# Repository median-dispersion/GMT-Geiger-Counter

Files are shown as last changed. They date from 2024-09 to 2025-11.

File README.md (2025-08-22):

# GMT-Geiger-Counter

## ⚠️ DISCLAIMER

This is a hobby project and should not be relied upon to accurately determine radiation levels, especially not if those radiation levels are potentially dangerous and or lethal!

## 🖼️ Images

<p align="center">
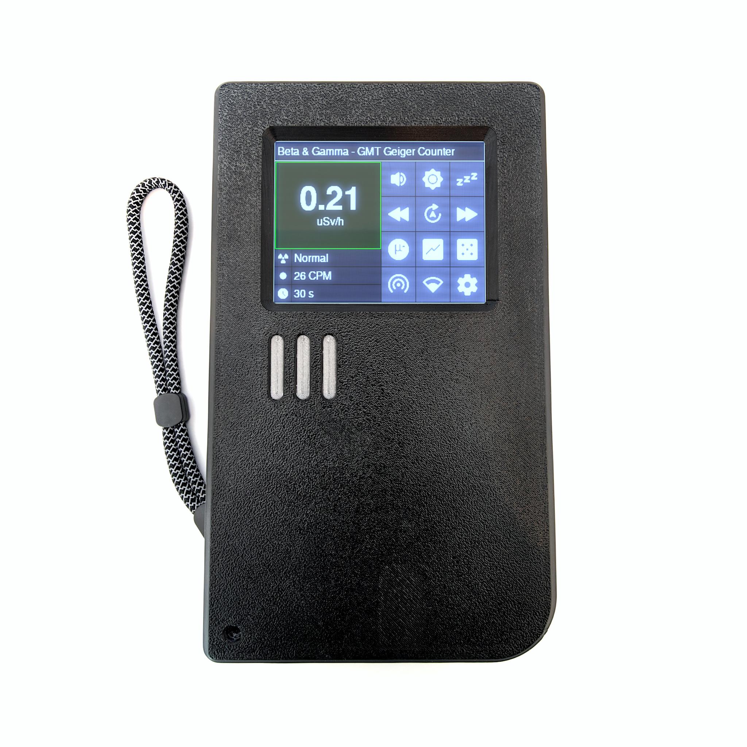
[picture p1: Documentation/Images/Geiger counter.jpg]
Geiger counter
    
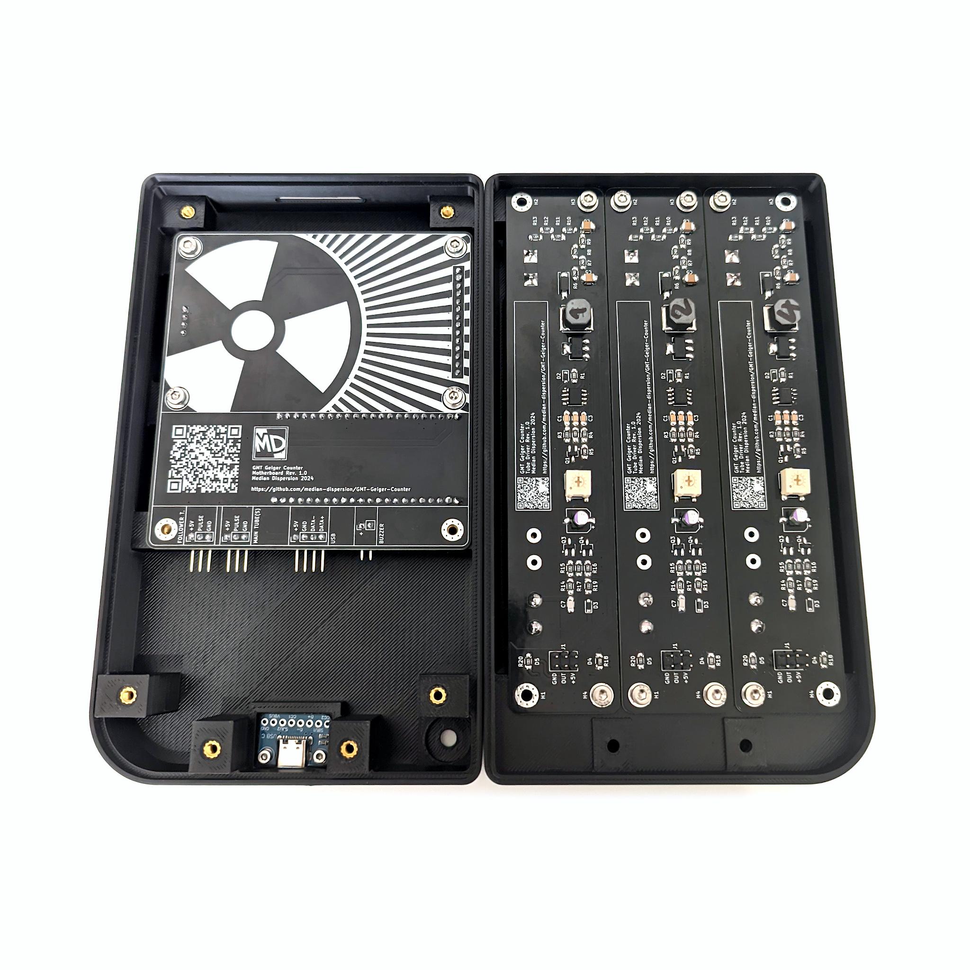
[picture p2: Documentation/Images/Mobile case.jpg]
Mobile case
    
    <br>
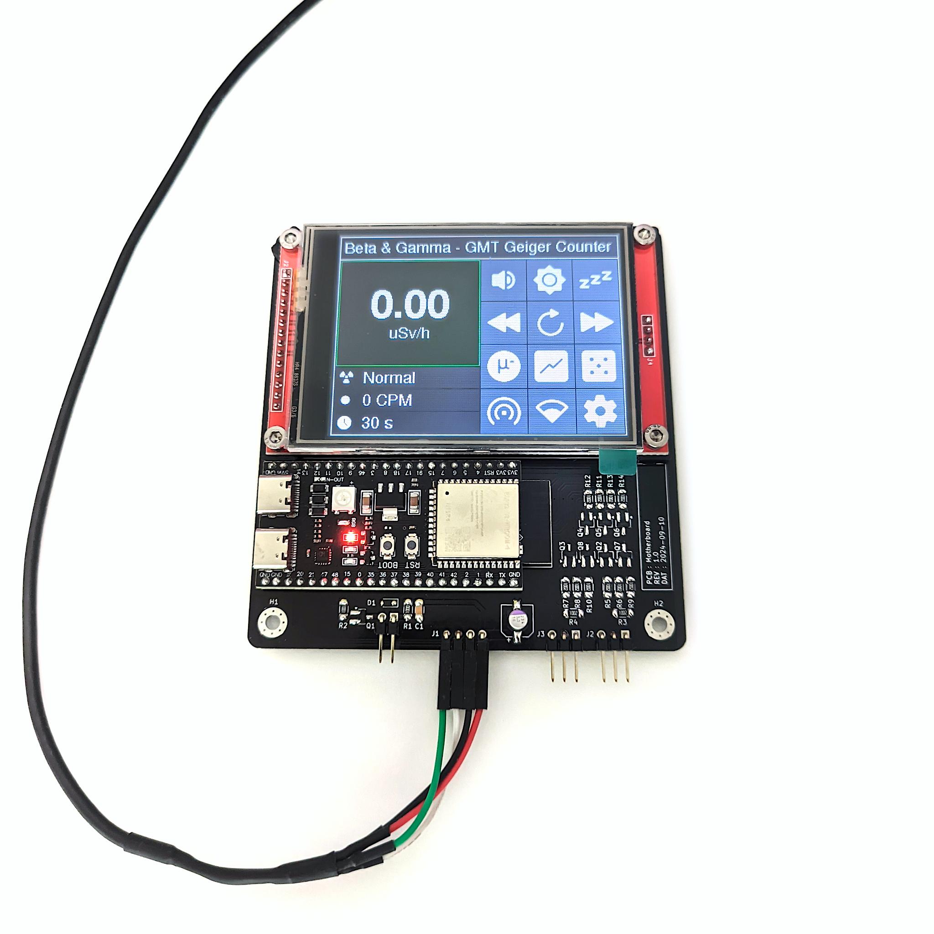
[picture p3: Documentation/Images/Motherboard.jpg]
Motherboard
    
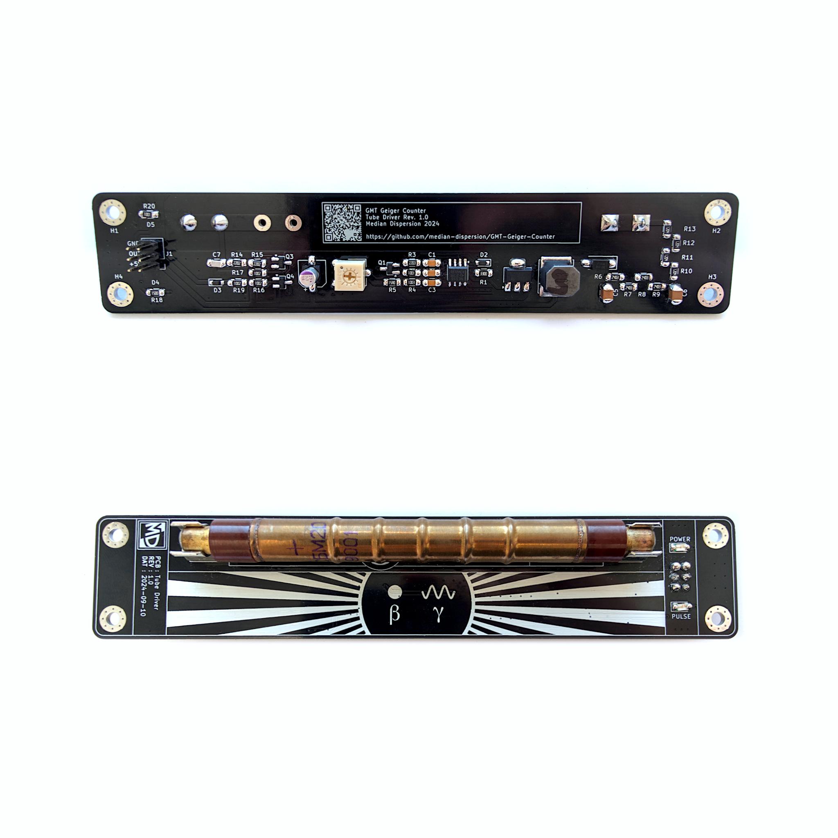
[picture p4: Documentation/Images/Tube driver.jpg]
Tube driver
    
</p>

## 📸 Screenshots

<p align="center">
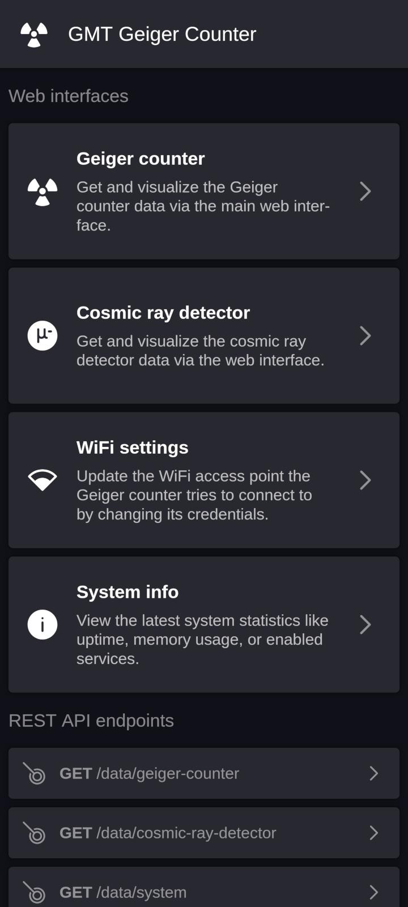
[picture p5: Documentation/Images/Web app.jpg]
Web app
    
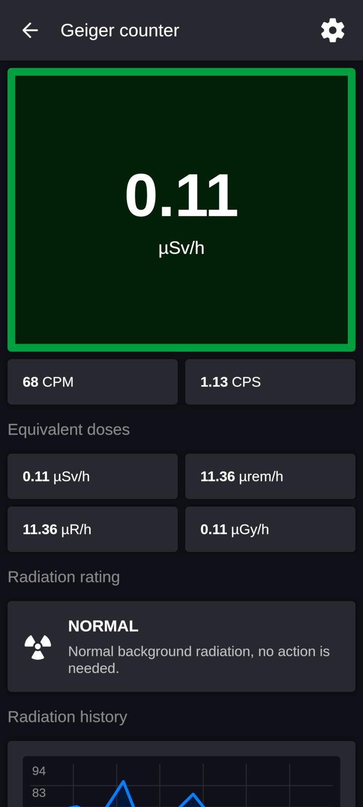
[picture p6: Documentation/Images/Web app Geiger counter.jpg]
Web app Geiger counter
    
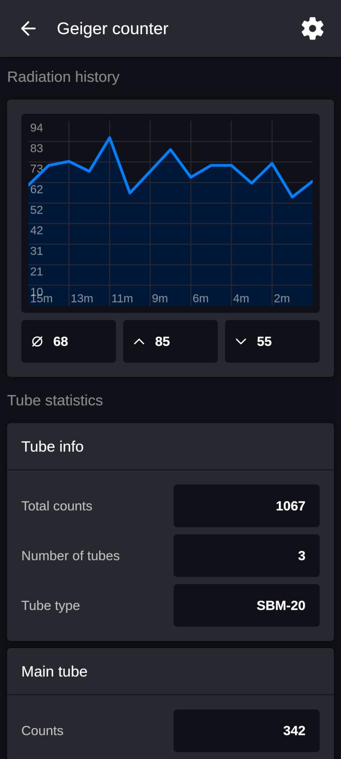
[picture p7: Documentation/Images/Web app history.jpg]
Web app history
    
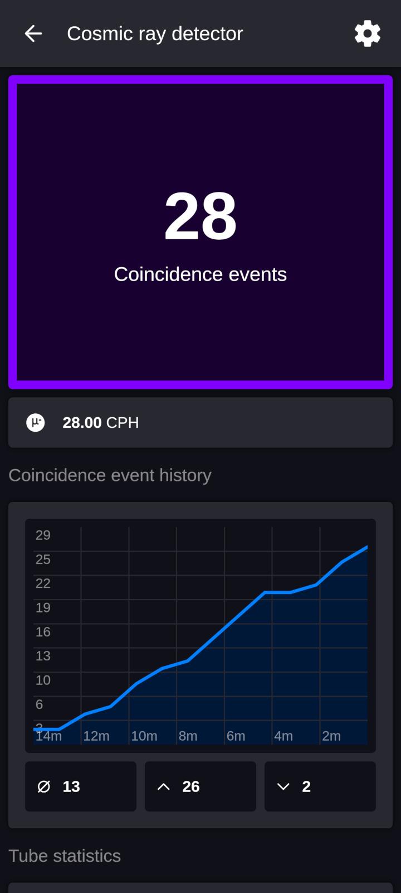
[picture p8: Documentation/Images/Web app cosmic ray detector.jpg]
Web app cosmic ray detector
    
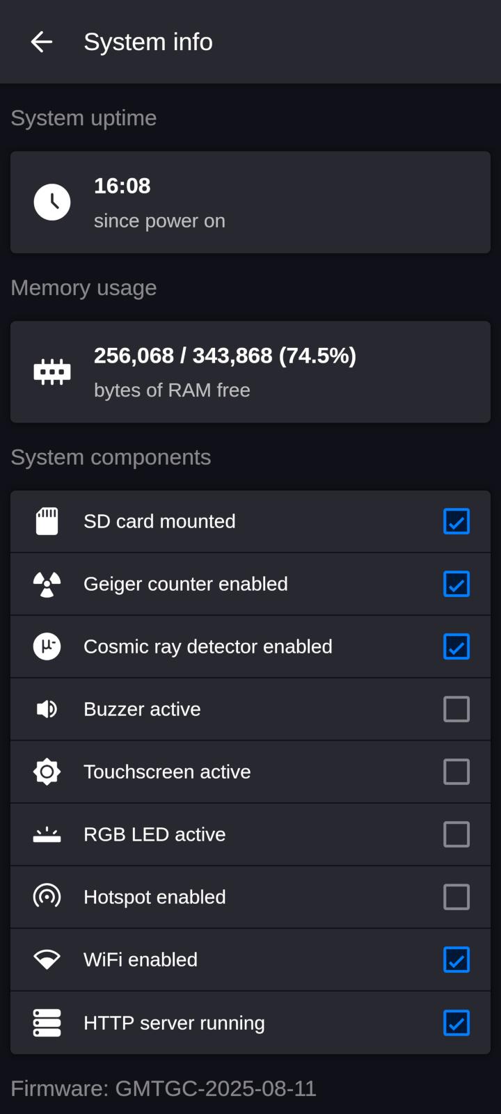
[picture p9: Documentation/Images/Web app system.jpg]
Web app system
    
</p>

## ⚙️ Features, Settings & Usage

### Geiger counter

#### Main Screen

The main Geiger counter display shows the equivalent dose, a radiation intensity rating, the counts-per-minute reading, and the integration time. From this screen, you can also access and navigate to all other system functions.

<p align="center">
    Geiger counter screen
</p>

| ID | Description |
| --- | --- |
| **1**  | **Main Equivalent Dose Screen** - Displays the equivalent dose in your selected unit, calculated over the current integration time. |
| **2**  | Tap the equivalent dose display to open the Geiger counter information section. |
| **3**  | Shows the current **radiation rating**. |
| **4**  | Displays the **counts per minute (CPM)** reading for the current integration time. |
| **5**  | **Integration Time** - The number of seconds the Geiger counter averages measurements to calculate CPM and equivalent dose. Shorter integration times provide more precise readings at high radiation levels; longer times are better for low radiation levels. The counter automatically adjusts this setting but it can also be manually increased or decreased. |
| **6**  | Tap to open the **audio settings**. |
| **7**  | Tap to open the **display settings**. |
| **8**  | Tap to enter **sleep mode**, which turns off the display and mutes all buzzer sounds. |
| **9**  | Tap to manually **decrease** the integration time. |
| **10** | Tap to **reset** the integration time to **automatic**. |
| **11** | Tap to manually **increase** the integration time. |
| **12** | Tap to enable and open the **cosmic ray detector**. |
| **13** | Tap to view **radiation history** in a graphical format. |
| **14** | Tap to enable and open the **true random number generator**. |
| **15** | Tap to open the **hotspot settings**. |
| **16** | Tap to open the **Wi-Fi settings**. |
| **17** | Tap to open the **system settings**. |

#### Geiger counter info screens

The Geiger counter info screen displays additional information about the recorded Geiger counter data, like the absolute number of counts or the total absorbed dose since power-on. In the settings section of this menu, you can also change Geiger counter properties like the measurement unit or if the measured value should auto-range.

<p align="center">
    Geiger counter counts screen
    Geiger counter absorbed dose screen
</p>

| ID | Descriptions |
| ----- | --- |
| **1** | **Total number of counts / total absorbed dose** - A sum of all counts or the total absorbed dose recorded since the device was powered on. This value only increases when the Geiger counter is enabled. |
| **2** | **Main Tube Detections** - The total number of detections or the total absorbed dose by the main tube since power-on. |
| **3** | **Follower Tube Detections** - The total number of detections or the total absorbed dose by the follower tube since power-on. |
| **4** | Tap to **view the previous page.** |
| **5** | Tap to **view the next page.** |
| **6** | Tap to **exit the Geiger counter info** and return to the Geiger counter screen. |

### Cosmic ray detector

The cosmic ray detector measures cosmic ray exposure by recording coincidence events, which are shown on this screen. While the detector is enabled, its data is also available via the serial console, the wireless API interface and the log file.

<p align="center">
    Cosmic ray detector screen
</p>

| ID | Description |
| ----- | --- |
| **1** | **Main Coincidence Events Screen** - Shows the total number of coincidence events recorded since the cosmic ray detector was enabled. This value resets when the cosmic ray detector is disabled. |
| **2** | **Coincidence Events per Hour** - Displays the hourly average since the cosmic ray detector was enabled. This value resets when the cosmic ray detector is disabled. |
| **3** | **Total Coincidence Events (Since Power-On)** - A sum of all coincidence events recorded since the device was powered on. This value only increases when the cosmic ray detector is enabled, but does not reset when it is disabled. |
| **4** | Tap to **temporarily mute detection sounds**. Tap again to re-enable them. This only mutes regular detection sounds; other alerts will still play. |
| **5** | Tap to enter **sleep mode**, which turns off the display and mutes all buzzer sounds. |
| **6** | **Main Tube Detections** - The total number of detections by the main tube since the cosmic ray detector was enabled. This value resets when the cosmic ray detector is disabled. |
| **7** | **Follower Tube Detections** - The total number of detections by the follower tube since the cosmic ray detector was enabled. This value resets when the cosmic ray detector is disabled. |
| **8** | Tap to **exit the cosmic ray detector** and return to the Geiger counter screen. A prompt will ask whether to disable the detector or keep it running in the background. |

### True random number generator

The true random number generator produces truly random numbers. You can set a custom range from 1 to 99, then roll to generate a number, which appears on the main result screen. While the generator is enabled, the Geiger counter is disabled. During this time, a continuous stream of random bits is also available via the serial console and wireless API interface.

<p align="center">
    True random number generator screen
</p>

| ID | Description |
| --- | --- |
| **1**  | **Main Result Screen** - Displays a true random number once the roll is complete. |
| **2**  | Tap to **increase the minimum value** of the result range. |
| **3**  | Tap to **increase the maximum value** of the result range. |
| **4**  | Shows the **minimum value** in the result range. |
| **5**  | Shows the **maximum value** in the result range. |
| **6**  | Tap to **decrease the minimum value** of the result range. |
| **7**  | Tap to **decrease the maximum value** of the result range. |
| **8**  | Tap to **roll a random number**. |
| **9**  | Tap to **temporarily mute detection sounds**. Tap again to re-enable them. This only mutes regular detection sounds; other alerts will still play. |
| **10** | Tap to enter **sleep mode**, which turns off the display and mutes all buzzer sounds. |
| **11** | Tap to **disable the true random number generator** and return to the Geiger counter screen. |

## ☁️ Web-App

All data recorded by the Geiger counter can also be accessed through a dedicated web app, which works in any modern browser on both PCs and smartphones. The app’s interface closely mirrors the main display on the Geiger counter itself, while also providing additional features such as extended graphical history with smoothing options. It is also required for tasks like updating Wi-Fi credentials.

To use the web app, an SD card containing the necessary files from the [firmware](Firmware/GMT-Geiger-Counter/SD%20Card/) folder must be inserted. Even without the app, the wireless API remains available, allowing data to be accessed through a browser; however, without the web app, the information will not be presented in a user-friendly format.

Screenshots of the web app can be found in the [screenshots](#-Screenshots) section.

## 🧩 Tube Compatibility

The tube driver PCB is compatible with a variety of Geiger-Müller tubes. Any tube that has a total length including the contacts of **110mm** to **107mm** or **90mm** to **87mm** and operates around **400V DC** should be physically compatible. Here are some tubes that will be compatible with this Geiger counter:

| Tube | Compatible | Tested | Note |
| --- | --- | --- | --- |
| SBM-20 | ✅ | ✅ | The tube this Geiger counter was designed for |
| STS-5 | ✅ | ❌ | The predecessor tube to the SBM-20 |
| J305 107mm | ✅ | ❌ | A modern alternative to the SBM-20 |
| J305 90mm  | ✅ | ❌ | A shorter version of the J305 107mm |
| M4011 | ✅ | ❌ | An alternative to the J305 90mm |

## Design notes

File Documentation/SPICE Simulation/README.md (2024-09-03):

# SPICE Simulation

## 💿 Softaware

The SPICE simulation software used for this project can be found at: https://www.falstad.com/circuit/circuitjs.html. It is an awesome interactive HTML5 / JavaScript web app developed by Paul Falstad and Iain Sharp and can be used directly in the browser.

## ⏬ Importing Circuits

To import a circuit, simply click on `File > Open File` and select the desired `.txt` file. Alternatively, open the chosen `.txt` file in a text editor and copy it's content, then click on `File > Import From Text`, paste the copied content into the text box and click `OK`.

## 🗒️ Note

Sometimes component values might differ from the ones used in the actual circuit, this is because the simulation is not always 100% accurate and through real world testing another value was determent to be more optimal.

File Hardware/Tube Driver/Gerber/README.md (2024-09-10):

# Tube Driver Gerber

## 🗓️ Date
2024-09-10

## ℹ️ Revision
1.0

## 💿 CAD Software
KiCad 8.0.5

## 🏗️ PCB Manufacturer
PCBWay (2-layer standard)

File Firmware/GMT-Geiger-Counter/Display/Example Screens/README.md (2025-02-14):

# Example screens

## ℹ️ Info

The files contained in this directory are GIMP projects used to design the Geiger counter interface. They are not used in the program code and are just a reference for positioning screen elements.

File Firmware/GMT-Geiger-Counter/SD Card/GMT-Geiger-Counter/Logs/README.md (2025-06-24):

# Log files

## ℹ️ Info

This directory contains JSON log files written by a GMT Geiger counter. To parse these log files use the [LogFileParser.py](/Tools/LogParser.py) python script contained the [Tools](/Tools) directory from the [GMT-Geiger-Counter](https://github.com/median-dispersion/GMT-Geiger-Counter) repository.

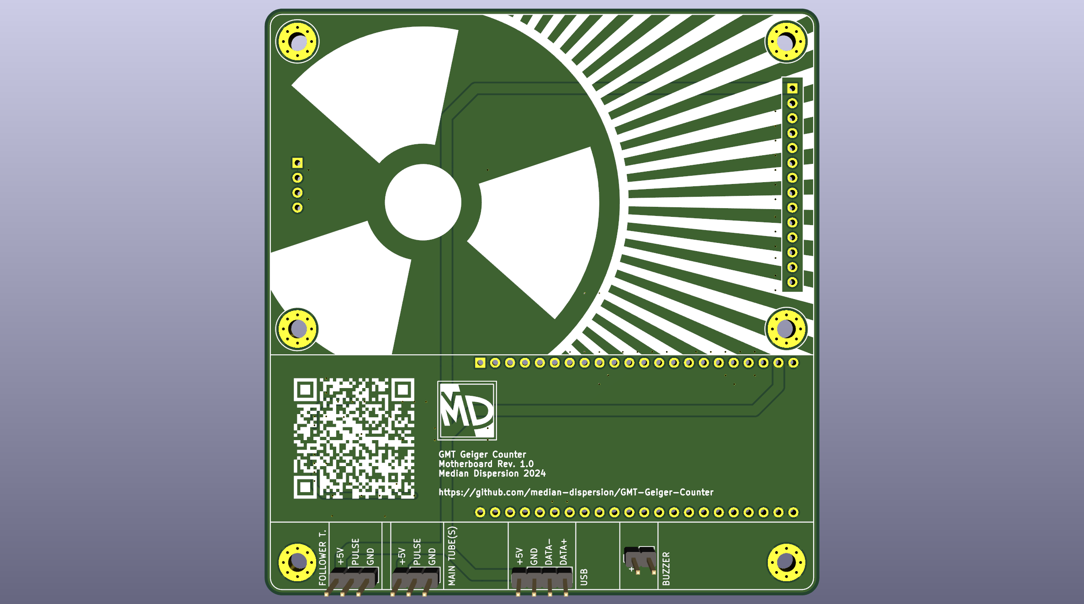
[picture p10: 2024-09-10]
Hardware/Motherboard/PCB Back - Motherboard.png

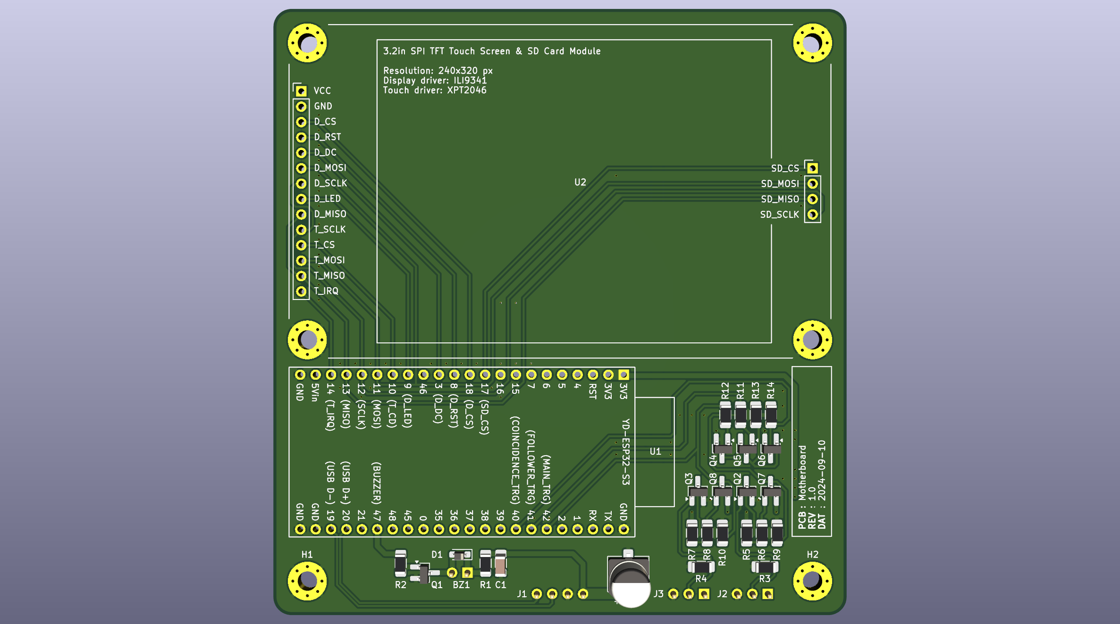
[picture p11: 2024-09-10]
Hardware/Motherboard/PCB Front - Motherboard.png

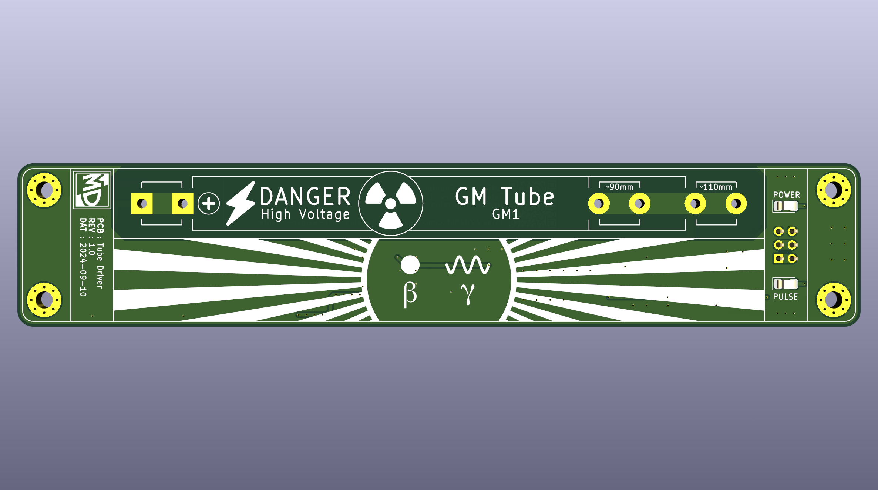
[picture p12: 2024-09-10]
Hardware/Tube Driver/PCB Back - Tube Driver.png

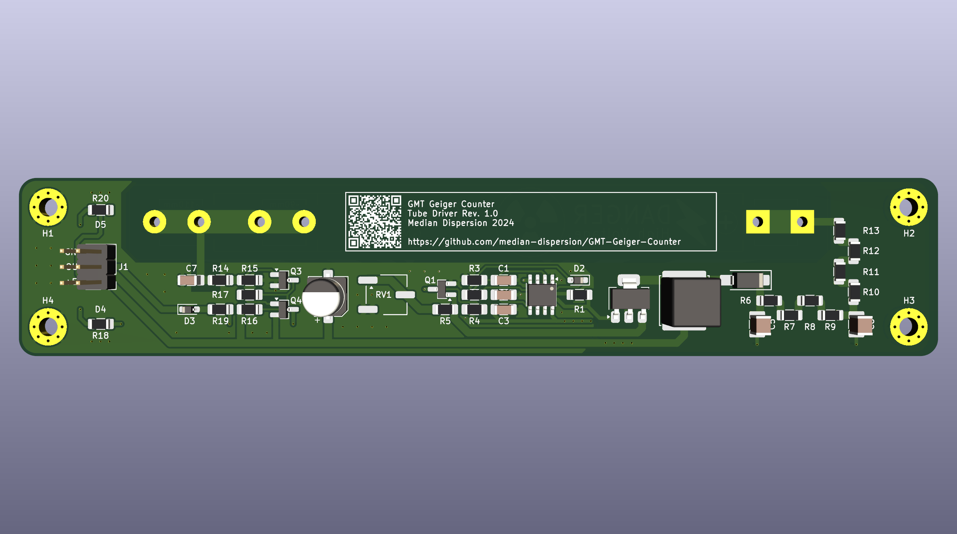
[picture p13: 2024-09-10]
Hardware/Tube Driver/PCB Front - Tube Driver.png

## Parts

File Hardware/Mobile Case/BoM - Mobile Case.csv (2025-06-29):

Component | Quantity | Metric thread | Length | Diameter
M3 Hex socket bolt | 6 | M3 | 28.0 mm | 5.5 mm
M3 Hex socket bolt | 14 | M3 | 11.0 mm | 5.5 mm
M3 Heat insert | 22 | M3 | 5.7 mm | 4.6 mm
M2 Hex socket bolt | 2 | M2 | 6.0 mm | 3.7 mm
M2 Heat insert | 2 | M2 | 4.0 mm | 3.5 mm

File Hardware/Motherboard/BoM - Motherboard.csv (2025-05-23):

Reference | Value | Qty | Footprint | MPN | Datasheet | DigiKey | Price (EUR)
BZ1 | Buzzer | 1 | Connector_PinHeader_2.54mm:PinHeader_1x02_P2.54mm_Vertical | WT-1209T | https://www.soberton.com/wp-content/uploads/2022/03/WT-1209T.pdf | https://www.digikey.com/en/products/detail/soberton-inc/WT-1209T/16384509 | 0,39€
C1 | 10nF | 1 | Capacitor_SMD:C_1206_3216Metric_Pad1.33x1.80mm_HandSolder | 885012208112 | https://www.we-online.com/components/products/datasheet/885012208112.pdf | https://www.digikey.com/en/products/detail/w%C3%BCrth-elektronik/885012208112/9345952 | 0,1€
C2 | 3.3uF | 1 | Capacitor_SMD:CP_Elec_6.3x5.4 | 16SVP3R3M | https://industrial.panasonic.com/ww/products/pt/os-con/models/16SVP3R3M | https://www.digikey.com/en/products/detail/panasonic-electronic-components/16svp3r3m/4204797 | 0,75€
D1 | 1N4148WS | 1 | Diode_SMD:D_SOD-323_HandSoldering | 1N4148WS | https://www.smc-diodes.com/propdf/1N4148WS%20N0572%20REV.B.pdf | https://www.digikey.com/en/products/detail/smc-diode-solutions/1N4148WS/6022449 | 0,09€
J1 | USB | 1 | Footprints:USB_Pin_Header | PH1RB-04-UA | https://app.adam-tech.com/products/download/data_sheet/201281/ph1rb-xx-ua-data-sheet.pdf | https://www.digikey.com/en/products/detail/adam-tech/PH1RB-04-UA/9830473 | 0,14€
J2 | FOLLOWER TUBE(S) | 1 | Connector_PinHeader_2.54mm:PinHeader_1x03_P2.54mm_Vertical | PH1RB-03-UA | https://app.adam-tech.com/products/download/data_sheet/201281/ph1rb-xx-ua-data-sheet.pdf | https://www.digikey.com/en/products/detail/adam-tech/PH1RB-03-UA/9830403 | 0,11€
J3 | MAIN TUBE(S) | 1 | Connector_PinHeader_2.54mm:PinHeader_1x03_P2.54mm_Vertical | PH1RB-03-UA | https://app.adam-tech.com/products/download/data_sheet/201281/ph1rb-xx-ua-data-sheet.pdf | https://www.digikey.com/en/products/detail/adam-tech/PH1RB-03-UA/9830403 | 0,11€
Q1 | MMBT3904 | 1 | Package_TO_SOT_SMD:SOT-23_Handsoldering | MMBT3904 | https://goodarksemi.com/docs/datasheets/transistors/MMBT3904.pdf | https://www.digikey.com/en/products/detail/good-ark-semiconductor/MMBT3904/18649092 | 0,09€
Q2 | MMBT3904 | 1 | Package_TO_SOT_SMD:SOT-23_Handsoldering | MMBT3904 | https://goodarksemi.com/docs/datasheets/transistors/MMBT3904.pdf | https://www.digikey.com/en/products/detail/good-ark-semiconductor/MMBT3904/18649092 | 0,09€
Q3 | MMBT3904 | 1 | Package_TO_SOT_SMD:SOT-23_Handsoldering | MMBT3904 | https://goodarksemi.com/docs/datasheets/transistors/MMBT3904.pdf | https://www.digikey.com/en/products/detail/good-ark-semiconductor/MMBT3904/18649092 | 0,09€
Q4 | MMBT3904 | 1 | Package_TO_SOT_SMD:SOT-23_Handsoldering | MMBT3904 | https://goodarksemi.com/docs/datasheets/transistors/MMBT3904.pdf | https://www.digikey.com/en/products/detail/good-ark-semiconductor/MMBT3904/18649092 | 0,09€
Q5 | MMBT3904 | 1 | Package_TO_SOT_SMD:SOT-23_Handsoldering | MMBT3904 | https://goodarksemi.com/docs/datasheets/transistors/MMBT3904.pdf | https://www.digikey.com/en/products/detail/good-ark-semiconductor/MMBT3904/18649092 | 0,09€
Q6 | MMBT3904 | 1 | Package_TO_SOT_SMD:SOT-23_Handsoldering | MMBT3904 | https://goodarksemi.com/docs/datasheets/transistors/MMBT3904.pdf | https://www.digikey.com/en/products/detail/good-ark-semiconductor/MMBT3904/18649092 | 0,09€
Q7 | MMBT3906 | 1 | Package_TO_SOT_SMD:SOT-23_Handsoldering | MMBT3906 | https://goodarksemi.com/docs/datasheets/transistors/MMBT3906.pdf | https://www.digikey.com/en/products/detail/good-ark-semiconductor/MMBT3906/18648958 | 0,09€
Q8 | MMBT3906 | 1 | Package_TO_SOT_SMD:SOT-23_Handsoldering | MMBT3906 | https://goodarksemi.com/docs/datasheets/transistors/MMBT3906.pdf | https://www.digikey.com/en/products/detail/good-ark-semiconductor/MMBT3906/18648958 | 0,09€
R1 | (Current Limit / Volume Adj.) | 1 | Resistor_SMD:R_1206_3216Metric_Pad1.30x1.75mm_HandSolder | RC1206JR-070RL | https://www.yageo.com/upload/media/product/products/datasheet/rchip/PYu-RC_Group_51_RoHS_L_12.pdf | https://www.digikey.com/en/products/detail/yageo/RC1206JR-070RL/729184 | 0,09€
R2 | 1k | 1 | Resistor_SMD:R_1206_3216Metric_Pad1.30x1.75mm_HandSolder | RC1206FR-071KL | https://www.yageo.com/upload/media/product/products/datasheet/rchip/PYu-RC_Group_51_RoHS_L_12.pdf | https://www.digikey.com/en/products/detail/yageo/RC1206FR-071KL/728387 | 0,09€
R3 | 10k | 1 | Resistor_SMD:R_1206_3216Metric_Pad1.30x1.75mm_HandSolder | RC1206FR-1310KL | https://www.yageo.com/upload/media/product/products/datasheet/rchip/PYu-RC_Group_51_RoHS_L_12.pdf | https://www.digikey.com/en/products/detail/yageo/RC1206FR-1310KL/13694071 | 0,09€
R4 | 10k | 1 | Resistor_SMD:R_1206_3216Metric_Pad1.30x1.75mm_HandSolder | RC1206FR-1310KL | https://www.yageo.com/upload/media/product/products/datasheet/rchip/PYu-RC_Group_51_RoHS_L_12.pdf | https://www.digikey.com/en/products/detail/yageo/RC1206FR-1310KL/13694071 | 0,09€
R5 | 10k | 1 | Resistor_SMD:R_1206_3216Metric_Pad1.30x1.75mm_HandSolder | RC1206FR-1310KL | https://www.yageo.com/upload/media/product/products/datasheet/rchip/PYu-RC_Group_51_RoHS_L_12.pdf | https://www.digikey.com/en/products/detail/yageo/RC1206FR-1310KL/13694071 | 0,09€
R6 | 10k | 1 | Resistor_SMD:R_1206_3216Metric_Pad1.30x1.75mm_HandSolder | RC1206FR-1310KL | https://www.yageo.com/upload/media/product/products/datasheet/rchip/PYu-RC_Group_51_RoHS_L_12.pdf | https://www.digikey.com/en/products/detail/yageo/RC1206FR-1310KL/13694071 | 0,09€
R7 | 10k | 1 | Resistor_SMD:R_1206_3216Metric_Pad1.30x1.75mm_HandSolder | RC1206FR-1310KL | https://www.yageo.com/upload/media/product/products/datasheet/rchip/PYu-RC_Group_51_RoHS_L_12.pdf | https://www.digikey.com/en/products/detail/yageo/RC1206FR-1310KL/13694071 | 0,09€
R8 | 10k | 1 | Resistor_SMD:R_1206_3216Metric_Pad1.30x1.75mm_HandSolder | RC1206FR-1310KL | https://www.yageo.com/upload/media/product/products/datasheet/rchip/PYu-RC_Group_51_RoHS_L_12.pdf | https://www.digikey.com/en/products/detail/yageo/RC1206FR-1310KL/13694071 | 0,09€
R9 | 10k | 1 | Resistor_SMD:R_1206_3216Metric_Pad1.30x1.75mm_HandSolder | RC1206FR-1310KL | https://www.yageo.com/upload/media/product/products/datasheet/rchip/PYu-RC_Group_51_RoHS_L_12.pdf | https://www.digikey.com/en/products/detail/yageo/RC1206FR-1310KL/13694071 | 0,09€
R10 | 10k | 1 | Resistor_SMD:R_1206_3216Metric_Pad1.30x1.75mm_HandSolder | RC1206FR-1310KL | https://www.yageo.com/upload/media/product/products/datasheet/rchip/PYu-RC_Group_51_RoHS_L_12.pdf | https://www.digikey.com/en/products/detail/yageo/RC1206FR-1310KL/13694071 | 0,09€
R11 | 10k | 1 | Resistor_SMD:R_1206_3216Metric_Pad1.30x1.75mm_HandSolder | RC1206FR-1310KL | https://www.yageo.com/upload/media/product/products/datasheet/rchip/PYu-RC_Group_51_RoHS_L_12.pdf | https://www.digikey.com/en/products/detail/yageo/RC1206FR-1310KL/13694071 | 0,09€
R12 | 10k | 1 | Resistor_SMD:R_1206_3216Metric_Pad1.30x1.75mm_HandSolder | RC1206FR-1310KL | https://www.yageo.com/upload/media/product/products/datasheet/rchip/PYu-RC_Group_51_RoHS_L_12.pdf | https://www.digikey.com/en/products/detail/yageo/RC1206FR-1310KL/13694071 | 0,09€
R13 | 10k | 1 | Resistor_SMD:R_1206_3216Metric_Pad1.30x1.75mm_HandSolder | RC1206FR-1310KL | https://www.yageo.com/upload/media/product/products/datasheet/rchip/PYu-RC_Group_51_RoHS_L_12.pdf | https://www.digikey.com/en/products/detail/yageo/RC1206FR-1310KL/13694071 | 0,09€
R14 | 10k | 1 | Resistor_SMD:R_1206_3216Metric_Pad1.30x1.75mm_HandSolder | RC1206FR-1310KL | https://www.yageo.com/upload/media/product/products/datasheet/rchip/PYu-RC_Group_51_RoHS_L_12.pdf | https://www.digikey.com/en/products/detail/yageo/RC1206FR-1310KL/13694071 | 0,09€
U1 | YD-ESP32-S3 N16R8 (ESP32-S3-DevKitC-1 USB-C Clone) | 1 | Footprints:YD-ESP32-S3_(ESP32-S3-DevKitC-1_USB-C_Clone) | YD-ESP32-S3 N16R8 | https://github.com/vcc-gnd/YD-ESP32-S3 | ~ | 8€
U2 | MSP3218 | 1 | Footprints:3.2in_SPI_TFT_Touch_Screen_&_SD_Card_Module | MSP3218 | ~ | ~ | 12€

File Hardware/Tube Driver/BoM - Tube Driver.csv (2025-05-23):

Reference | Value | Qty | Footprint | MPN | Datasheet | DigiKey | Price (EUR)
C1 | 1nF | 1 | Capacitor_SMD:C_1206_3216Metric_Pad1.33x1.80mm_HandSolder | 885012208046 | https://www.we-online.com/components/products/datasheet/885012208046.pdf | https://www.digikey.com/en/products/detail/w%C3%BCrth-elektronik/885012208046/5453957 | 0,09€
C2 | 10nF | 1 | Capacitor_SMD:C_1206_3216Metric_Pad1.33x1.80mm_HandSolder | 885012208112 | https://www.we-online.com/components/products/datasheet/885012208112.pdf | https://www.digikey.com/en/products/detail/w%C3%BCrth-elektronik/885012208112/9345952 | 0,1€
C3 | 10nF | 1 | Capacitor_SMD:C_1206_3216Metric_Pad1.33x1.80mm_HandSolder | 885012208112 | https://www.we-online.com/components/products/datasheet/885012208112.pdf | https://www.digikey.com/en/products/detail/w%C3%BCrth-elektronik/885012208112/9345952 | 0,1€
C4 | 3.3uF | 1 | Capacitor_SMD:CP_Elec_6.3x5.4 | 16SVP3R3M | https://industrial.panasonic.com/ww/products/pt/os-con/models/16SVP3R3M | https://www.digikey.com/en/products/detail/panasonic-electronic-components/16svp3r3m/4204797 | 0,75€
C5 | 47nF | 1 | Capacitor_SMD:C_1210_3225Metric_Pad1.33x2.70mm_HandSolder | C1210V473KDRAC7800 | https://search.kemet.com/download/datasheet/C1210V473KDRAC7800 | https://www.digikey.com/en/products/detail/kemet/C1210V473KDRAC7800/3079051 | 0,31€
C6 | 47nF | 1 | Capacitor_SMD:C_1210_3225Metric_Pad1.33x2.70mm_HandSolder | C1210V473KDRAC7800 | https://search.kemet.com/download/datasheet/C1210V473KDRAC7800 | https://www.digikey.com/en/products/detail/kemet/C1210V473KDRAC7800/3079051 | 0,31€
C7 | 820pF | 1 | Capacitor_SMD:C_1206_3216Metric_Pad1.33x1.80mm_HandSolder | CC1206FRNPO9BN821 | https://www.yageo.com/upload/media/product/productsearch/datasheet/mlcc/UPY-GP_NP0_16V-to-50V_18.pdf | https://www.digikey.com/en/products/detail/yageo/CC1206FRNPO9BN821/11492021 | 0,45€
D1 | RS1J | 1 | Footprints:D_SMA_HV_Handsoldering | RS1J-13-F | https://www.diodes.com/assets/Datasheets/ds15002.pdf | https://www.digikey.com/en/products/detail/diodes-incorporated/RS1J-13-F/749974 | 0,4€
D2 | 1N914BWS | 1 | Diode_SMD:D_SOD-323_HandSoldering | 1N914BWS | https://rocelec.widen.net/view/pdf/tf3dlteblx/FAIR-S-A0000573112-1.pdf?t.download=true&u=5oefqw | https://www.digikey.com/en/products/detail/onsemi/1N914BWS/1873807 | 0,14€
D3 | RB751V-40 | 1 | Diode_SMD:D_SOD-323_HandSoldering | RB751V-40_R1_00001 | https://www.panjit.com.tw/upload/datasheet/RB751V-40.pdf | https://www.digikey.com/en/products/detail/panjit-international-inc/RB751V-40-R1-00001/14661067 | 0,14€
D4 | GREEN | 1 | LED_SMD:LED_1206_3216Metric_Pad1.42x1.75mm_HandSolder | 150120GS75000 | https://www.we-online.com/components/products/datasheet/150120GS75000.pdf | https://www.digikey.com/en/products/detail/w%C3%BCrth-elektronik/150120GS75000/4489936 | 0,2€
D5 | RED | 1 | LED_SMD:LED_1206_3216Metric_Pad1.42x1.75mm_HandSolder | 150120RS75000 | https://www.we-online.com/components/products/datasheet/150120RS75000.pdf | https://www.digikey.com/en/products/detail/w%C3%BCrth-elektronik/150120RS75000/4489939 | 0,2€
GM1 | Geiger-Müller Tube | 1 | Footprints:GM_Tube_Mount | FC-102 BRIGHT TIN | https://www.belfuse.com/resources/datasheets/circuitprotection/ds-cp-0672-fuse-clips-series.pdf | https://www.digikey.com/en/products/detail/bel-fuse-inc/FC-102-BRIGHT-TIN/622585 | 0,1€
J1 | I/O | 1 | Connector_PinHeader_2.54mm:PinHeader_2x03_P2.54mm_Vertical | PH2-06-UA | https://app.adam-tech.com/products/download/data_sheet/202065/ph2-xx-ua-data-sheet.pdf | https://www.digikey.com/en/products/detail/adam-tech/PH2-06-UA/9830396 | 0,11€
L1 | 10mH | 1 | Footprints:L_8065_HandSolder | 74404086103 | https://www.we-online.com/components/products/datasheet/74404086103.pdf | https://www.digikey.com/en/products/detail/w%C3%BCrth-elektronik/74404086103/6598069 | 1,13€
Q1 | MMBT3904 | 1 | Package_TO_SOT_SMD:SOT-23_Handsoldering | MMBT3904 | https://goodarksemi.com/docs/datasheets/transistors/MMBT3904.pdf | https://www.digikey.com/en/products/detail/good-ark-semiconductor/MMBT3904/18649092 | 0,09€
Q2 | STN2580 | 1 | Package_TO_SOT_SMD:SOT-223 | STN2580 | https://www.st.com/content/ccc/resource/technical/document/datasheet/83/0b/b4/e4/ea/98/4a/58/DM00068906.pdf/files/DM00068906.pdf/jcr:content/translations/en.D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 | https://www.digikey.com/en/products/detail/stmicroelectronics/STN2580/3874239 | 0,48€
Q3 | MMBT3904 | 1 | Package_TO_SOT_SMD:SOT-23_Handsoldering | MMBT3904 | https://goodarksemi.com/docs/datasheets/transistors/MMBT3904.pdf | https://www.digikey.com/en/products/detail/good-ark-semiconductor/MMBT3904/18649092 | 0,09€
Q4 | MMBT3906 | 1 | Package_TO_SOT_SMD:SOT-23_Handsoldering | MMBT3906 | https://goodarksemi.com/docs/datasheets/transistors/MMBT3906.pdf | https://www.digikey.com/en/products/detail/good-ark-semiconductor/MMBT3906/18648958 | 0,09€
R1 | 330 | 1 | Resistor_SMD:R_1206_3216Metric_Pad1.30x1.75mm_HandSolder | RC1206FR-07330RL | https://www.yageo.com/upload/media/product/products/datasheet/rchip/PYu-RC_Group_51_RoHS_L_12.pdf | https://www.digikey.com/en/products/detail/yageo/RC1206FR-07330RL/728822 | 0,09€
R2 | 1k | 1 | Resistor_SMD:R_1206_3216Metric_Pad1.30x1.75mm_HandSolder | RC1206FR-071KL | https://www.yageo.com/upload/media/product/products/datasheet/rchip/PYu-RC_Group_51_RoHS_L_12.pdf | https://www.digikey.com/en/products/detail/yageo/RC1206FR-071KL/728387 | 0,09€
R3 | 220k | 1 | Resistor_SMD:R_1206_3216Metric_Pad1.30x1.75mm_HandSolder | RC1206FR-07220KL | https://www.yageo.com/upload/media/product/products/datasheet/rchip/PYu-RC_Group_51_RoHS_L_12.pdf | https://www.digikey.com/en/products/detail/yageo/RC1206FR-07220KL/728694 | 0,09€
R4 | 100k | 1 | Resistor_SMD:R_1206_3216Metric_Pad1.30x1.75mm_HandSolder | RC1206FR-07100KL | https://www.yageo.com/upload/media/product/products/datasheet/rchip/PYu-RC_Group_51_RoHS_L_12.pdf | https://www.digikey.com/en/products/detail/yageo/RC1206FR-07100KL/728492 | 0,09€
R5 | 15 | 1 | Resistor_SMD:R_1206_3216Metric_Pad1.30x1.75mm_HandSolder | RC1206FR-0715RL | https://www.yageo.com/upload/media/product/products/datasheet/rchip/PYu-RC_Group_51_RoHS_L_12.pdf | https://www.digikey.com/en/products/detail/yageo/RC1206FR-0715RL/728555 | 0,09€
R6 | 240k | 1 | Resistor_SMD:R_1206_3216Metric_Pad1.30x1.75mm_HandSolder | RC1206FR-07240KL | https://www.yageo.com/upload/media/product/products/datasheet/rchip/PYu-RC_Group_51_RoHS_L_12.pdf | https://www.digikey.com/en/products/detail/yageo/RC1206FR-07240KL/728714 | 0,09€
R7 | 240k | 1 | Resistor_SMD:R_1206_3216Metric_Pad1.30x1.75mm_HandSolder | RC1206FR-07240KL | https://www.yageo.com/upload/media/product/products/datasheet/rchip/PYu-RC_Group_51_RoHS_L_12.pdf | https://www.digikey.com/en/products/detail/yageo/RC1206FR-07240KL/728714 | 0,09€
R8 | 240k | 1 | Resistor_SMD:R_1206_3216Metric_Pad1.30x1.75mm_HandSolder | RC1206FR-07240KL | https://www.yageo.com/upload/media/product/products/datasheet/rchip/PYu-RC_Group_51_RoHS_L_12.pdf | https://www.digikey.com/en/products/detail/yageo/RC1206FR-07240KL/728714 | 0,09€
R9 | 240k | 1 | Resistor_SMD:R_1206_3216Metric_Pad1.30x1.75mm_HandSolder | RC1206FR-07240KL | https://www.yageo.com/upload/media/product/products/datasheet/rchip/PYu-RC_Group_51_RoHS_L_12.pdf | https://www.digikey.com/en/products/detail/yageo/RC1206FR-07240KL/728714 | 0,09€
R10 | 1.2M | 1 | Resistor_SMD:R_1206_3216Metric_Pad1.30x1.75mm_HandSolder | RC1206FR-071M2L | https://www.yageo.com/upload/media/product/products/datasheet/rchip/PYu-RC_Group_51_RoHS_L_12.pdf | https://www.digikey.com/en/products/detail/yageo/RC1206FR-071M2L/728412 | 0,09€
R11 | 1.2M | 1 | Resistor_SMD:R_1206_3216Metric_Pad1.30x1.75mm_HandSolder | RC1206FR-071M2L | https://www.yageo.com/upload/media/product/products/datasheet/rchip/PYu-RC_Group_51_RoHS_L_12.pdf | https://www.digikey.com/en/products/detail/yageo/RC1206FR-071M2L/728412 | 0,09€
R12 | 1.2M | 1 | Resistor_SMD:R_1206_3216Metric_Pad1.30x1.75mm_HandSolder | RC1206FR-071M2L | https://www.yageo.com/upload/media/product/products/datasheet/rchip/PYu-RC_Group_51_RoHS_L_12.pdf | https://www.digikey.com/en/products/detail/yageo/RC1206FR-071M2L/728412 | 0,09€
R13 | 1.2M | 1 | Resistor_SMD:R_1206_3216Metric_Pad1.30x1.75mm_HandSolder | RC1206FR-071M2L | https://www.yageo.com/upload/media/product/products/datasheet/rchip/PYu-RC_Group_51_RoHS_L_12.pdf | https://www.digikey.com/en/products/detail/yageo/RC1206FR-071M2L/728412 | 0,09€
R14 | 22k | 1 | Resistor_SMD:R_1206_3216Metric_Pad1.30x1.75mm_HandSolder | RC1206FR-0722KL | https://www.yageo.com/upload/media/product/products/datasheet/rchip/PYu-RC_Group_51_RoHS_L_12.pdf | https://www.digikey.com/en/products/detail/yageo/RC1206FR-0722KL/728688 | 0,09€
R15 | 22k | 1 | Resistor_SMD:R_1206_3216Metric_Pad1.30x1.75mm_HandSolder | RC1206FR-0722KL | https://www.yageo.com/upload/media/product/products/datasheet/rchip/PYu-RC_Group_51_RoHS_L_12.pdf | https://www.digikey.com/en/products/detail/yageo/RC1206FR-0722KL/728688 | 0,09€
R16 | 10k | 1 | Resistor_SMD:R_1206_3216Metric_Pad1.30x1.75mm_HandSolder | RC1206FR-1310KL | https://www.yageo.com/upload/media/product/products/datasheet/rchip/PYu-RC_Group_51_RoHS_L_12.pdf | https://www.digikey.com/en/products/detail/yageo/RC1206FR-1310KL/13694071 | 0,09€
R17 | 10k | 1 | Resistor_SMD:R_1206_3216Metric_Pad1.30x1.75mm_HandSolder | RC1206FR-1310KL | https://www.yageo.com/upload/media/product/products/datasheet/rchip/PYu-RC_Group_51_RoHS_L_12.pdf | https://www.digikey.com/en/products/detail/yageo/RC1206FR-1310KL/13694071 | 0,09€
R18 | 150 | 1 | Resistor_SMD:R_1206_3216Metric_Pad1.30x1.75mm_HandSolder | RC1206FR-13150RL | https://www.yageo.com/upload/media/product/products/datasheet/rchip/PYu-RC_Group_51_RoHS_L_12.pdf | https://www.digikey.com/en/products/detail/yageo/RC1206FR-13150RL/14286527 | 0,09€
R19 | 10k | 1 | Resistor_SMD:R_1206_3216Metric_Pad1.30x1.75mm_HandSolder | RC1206FR-1310KL | https://www.yageo.com/upload/media/product/products/datasheet/rchip/PYu-RC_Group_51_RoHS_L_12.pdf | https://www.digikey.com/en/products/detail/yageo/RC1206FR-1310KL/13694071 | 0,09€
R20 | 1k | 1 | Resistor_SMD:R_1206_3216Metric_Pad1.30x1.75mm_HandSolder | RC1206FR-071KL | https://www.yageo.com/upload/media/product/products/datasheet/rchip/PYu-RC_Group_51_RoHS_L_12.pdf | https://www.digikey.com/en/products/detail/yageo/RC1206FR-071KL/728387 | 0,09€
RV1 | 10 | 1 | Footprints:RV_3361P | 3361P-1-100GLF | https://www.bourns.com/docs/Product-Datasheets/3361.pdf | https://www.digikey.com/en/products/detail/bourns-inc/3361P-1-100GLF/1817605 | 1,14€
U1 | NE555D | 1 | Package_SO:SOIC-8_3.9x4.9mm_P1.27mm | NE555D | https://rocelec.widen.net/view/pdf/giqzbewdkx/slfs022i.pdf?t.download=true&u=5oefqw | https://www.digikey.com/en/products/detail/texas-instruments/NE555D/280641 | 0,89€

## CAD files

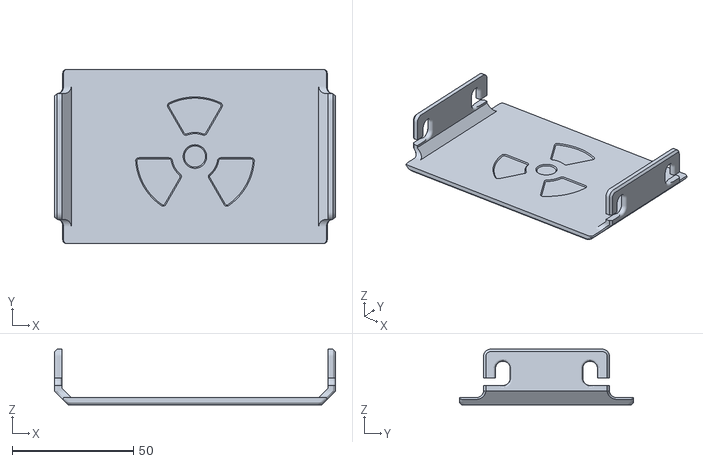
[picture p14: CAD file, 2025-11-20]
Hardware/Mobile Case/STL/Display Cover.stl
116.0 x 72.0 x 23.0

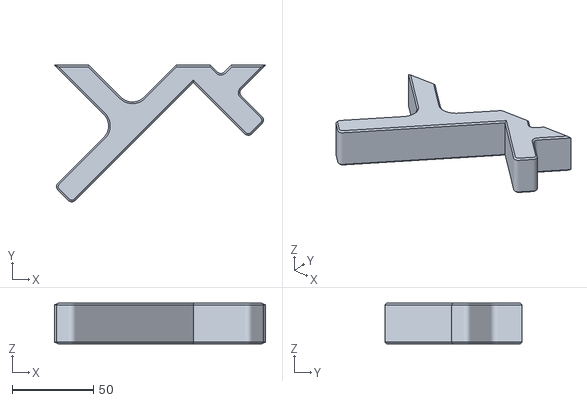
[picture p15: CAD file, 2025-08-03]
Hardware/Mobile Case/STL/45 Degree Case Stand x1.stl
130.1 x 84.3 x 25.0

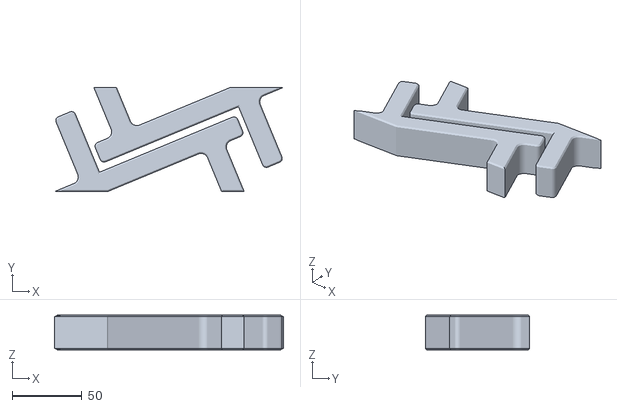
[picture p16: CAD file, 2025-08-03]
Hardware/Mobile Case/STL/22.5 Degree Case Stand x2.stl
164.0 x 74.6 x 25.0

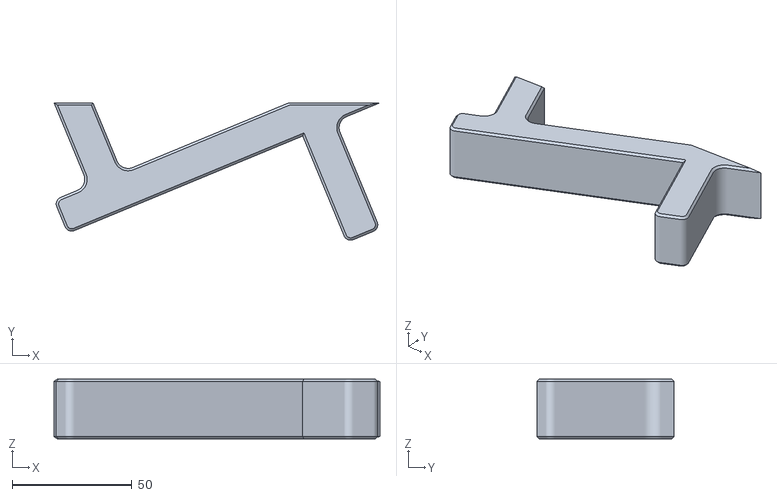
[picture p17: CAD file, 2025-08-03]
Hardware/Mobile Case/STL/22.5 Degree Case Stand x1.stl
135.9 x 57.3 x 25.0

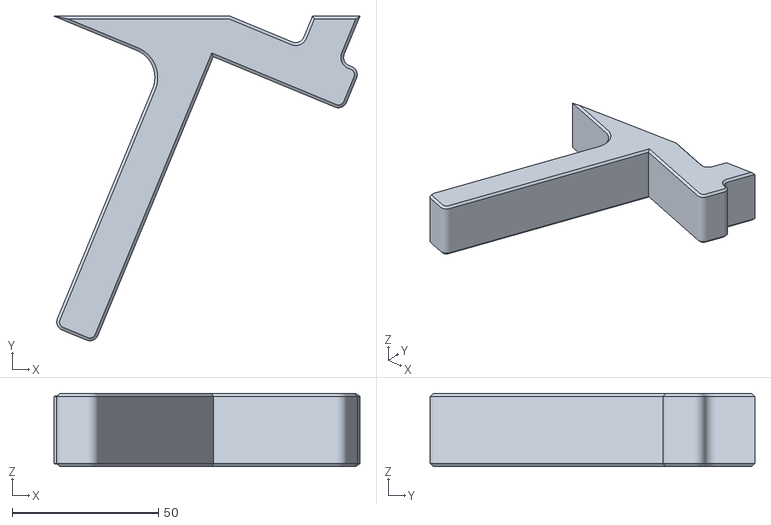
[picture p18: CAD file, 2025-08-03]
Hardware/Mobile Case/STL/67.5 Degree Case Stand x1.stl
104.5 x 110.9 x 25.0

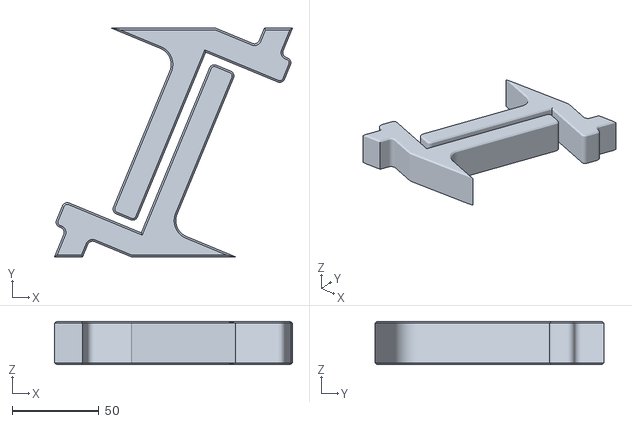
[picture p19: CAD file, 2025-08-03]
Hardware/Mobile Case/STL/67.5 Degree Case Stand x2.stl
137.4 x 132.0 x 25.0

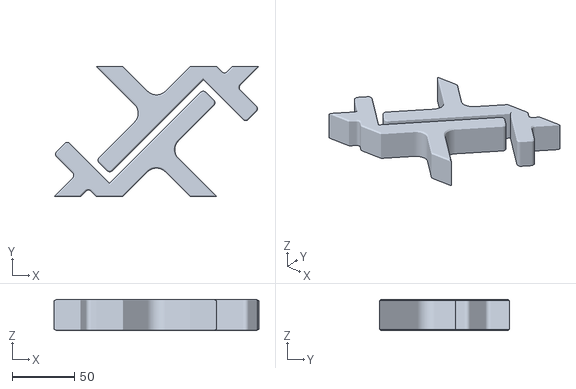
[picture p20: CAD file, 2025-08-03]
Hardware/Mobile Case/STL/45 Degree Case Stand x2.stl
164.1 x 104.1 x 25.0

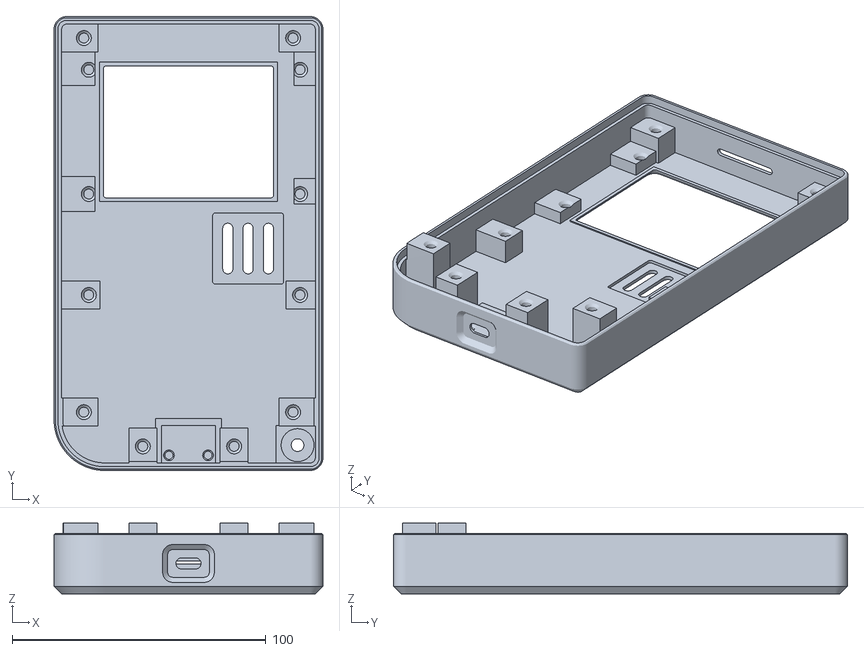
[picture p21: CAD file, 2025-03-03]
Hardware/Mobile Case/STL/Top Shell.stl
106.0 x 179.0 x 27.9

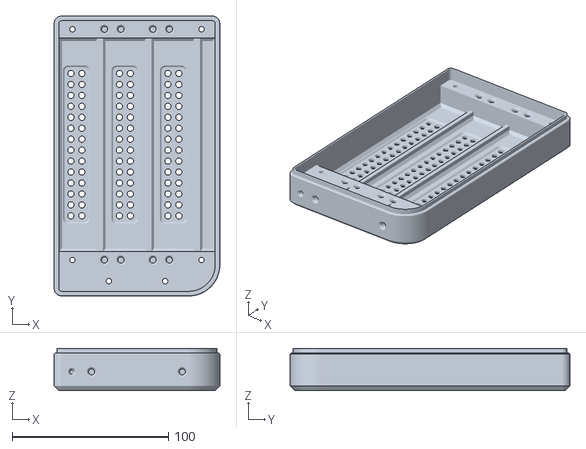
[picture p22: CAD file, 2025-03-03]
Hardware/Mobile Case/STL/Bottom Shell Triple Tube.stl
106.0 x 179.0 x 27.0

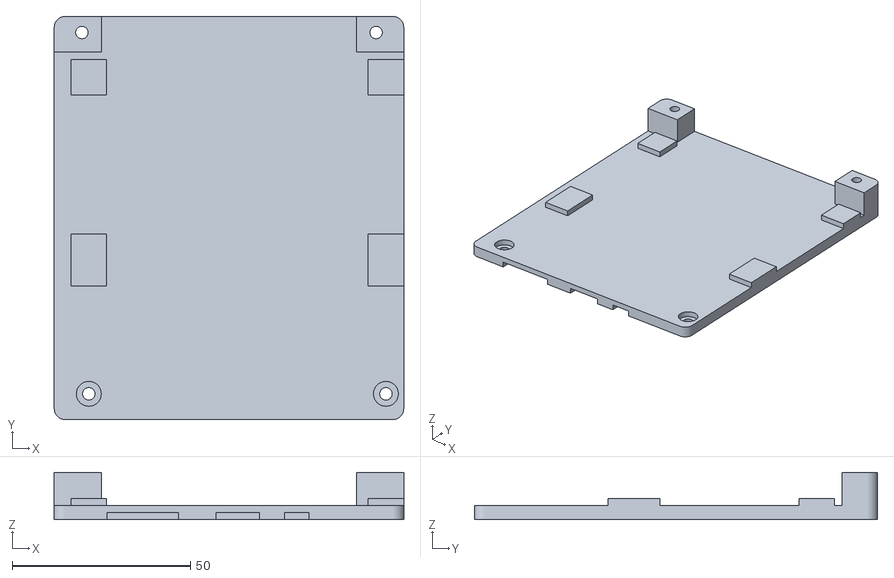
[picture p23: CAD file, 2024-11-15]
Hardware/Mobile Case/STL/HV Shield.stl
98.0 x 113.0 x 13.3

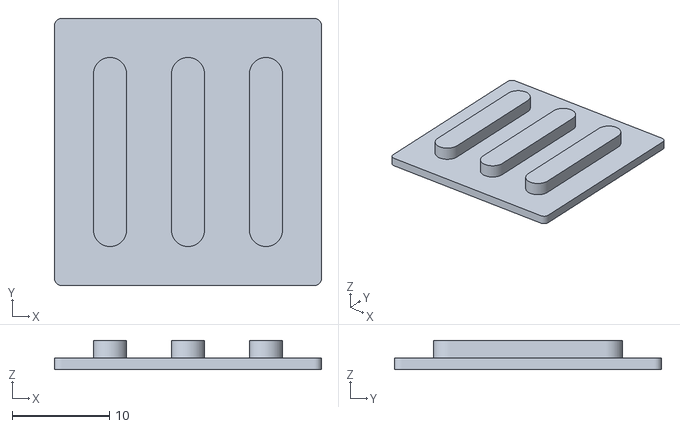
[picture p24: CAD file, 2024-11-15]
Hardware/Mobile Case/STL/Light Pipes.stl
27.4 x 27.4 x 3.00

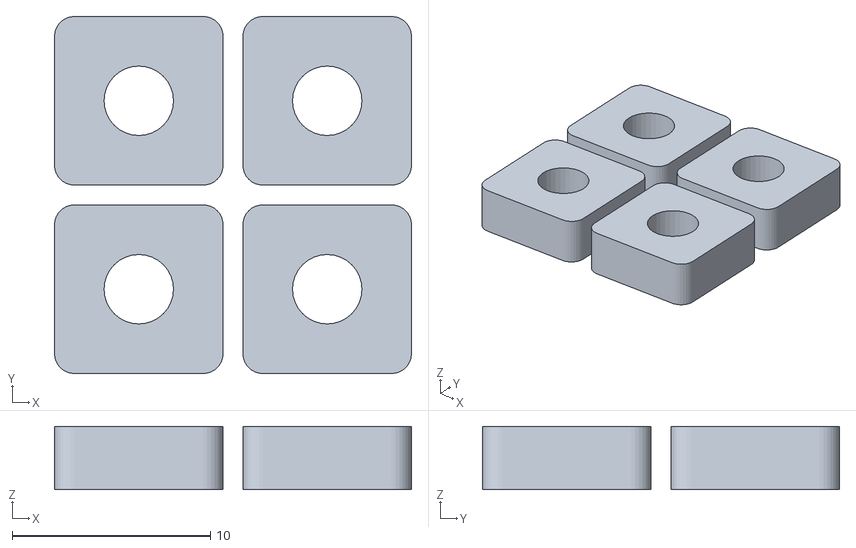
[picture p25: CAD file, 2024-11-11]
Hardware/Mobile Case/STL/Display Spacer x4.stl
18.0 x 18.0 x 3.20

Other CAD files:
Hardware/Mobile Case/STL/Bottom Shell Double Tube.stl
Hardware/Mobile Case/Case Stands.blend
Hardware/Mobile Case/Mobile Case.blend

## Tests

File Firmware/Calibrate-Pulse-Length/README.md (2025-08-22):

# Firmware: Calibrate-Pulse-Length

## ℹ️ Info

This firmware will create the pulse length calibration values for a specific Geiger-Müller tube. To get an accurate reading from a tube, the calibration values must be known. These values can then be used in the main Geiger counter firmware [configuration](/Firmware/GMT-Geiger-Counter/Configuration.h) file. The median pulse length for an SBM-20 tube is around 122 µs, but this might differ for different tubes.

## 📋 Instructions

Open the [Calibrate-Pulse-Length.ino](/Firmware/Calibrate-Pulse-Length/Calibrate-Pulse-Length.ino) firmware file inside the Arduino IDE. Plug in the ESP32 S3 via the onboard USB port and verify that the ESP32 boards are installed via the board manager. Under `Tools > Boards > esp32` select the `ESP32S3 Dev Module` then go to `Tools > Port` and select the appropriate port. Flash the firmware by clicking `Upload`. Open up the serial console via `Tools > Serial Monitor` set the baud rate to `115200` and wait until the sample collection is finished. The calibration values will be displayed when the defined number of samples are taken.

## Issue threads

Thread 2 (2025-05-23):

Decoupling capacitor inrush current too large for some USB power supplies

median-dispersion, 2025-05-23:
The decoupling capacitors "C2" on the motherboard and "C4" on the tube driver board are causing excessive inrush current, which causes some USB power supplies to trip OCP. Change it to a more reasonable 3.3uF capacitor.

median-dispersion, 2025-05-23:
3925e8760f84a1cf365fe5f74f79bf00b0989665

Closed 2025-05-23.

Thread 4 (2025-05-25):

Outdated PCB files

median-dispersion, 2025-05-25:
# Issue

Issue: #2
Commit: 3925e8760f84a1cf365fe5f74f79bf00b0989665

After the decoupling capacitor values were changed on the schematic files, the PCB files were not updated! Update the decoupling capacitor values on the PCB files and regenerate the Gerber files.

# Files that need to be changed:

[Motherboard.kicad_pcb](https://github.com/median-dispersion/GMT-Geiger-Counter/blob/main/Hardware/Motherboard/KiCad/Motherboard.kicad_pcb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)
[Motherboard/Gerber/*](https://github.com/median-dispersion/GMT-Geiger-Counter/tree/main/Hardware/Motherboard/Gerber)
[Tube Driver.kicad_pcb](https://github.com/median-dispersion/GMT-Geiger-Counter/blob/main/Hardware/Tube%20Driver/KiCad/Tube%20Driver.kicad_pcb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)
[Tube Driver/Gerber/*](https://github.com/median-dispersion/GMT-Geiger-Counter/blob/main/Hardware/Tube%20Driver/Gerber)

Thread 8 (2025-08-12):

Coincidence detection is using inappropriate detection logic

median-dispersion, 2025-08-12:
# Issue

After the multi-tube support was implemented in 3c0947996c16baec95c4e11b8e1fe559de884c73 the coincidence detection was updated to the new logic as well, which is not appropriate to detect single cosmic ray events. A new tube type for coincidence events should be created that uses the previous tube logic for detecting events.

median-dispersion, 2025-09-21:
Fixed in 48e9c2114f06fd1d218044166f70cfe29d24492f with firmware version GMTGC-2025-09-21

Closed 2025-09-21.

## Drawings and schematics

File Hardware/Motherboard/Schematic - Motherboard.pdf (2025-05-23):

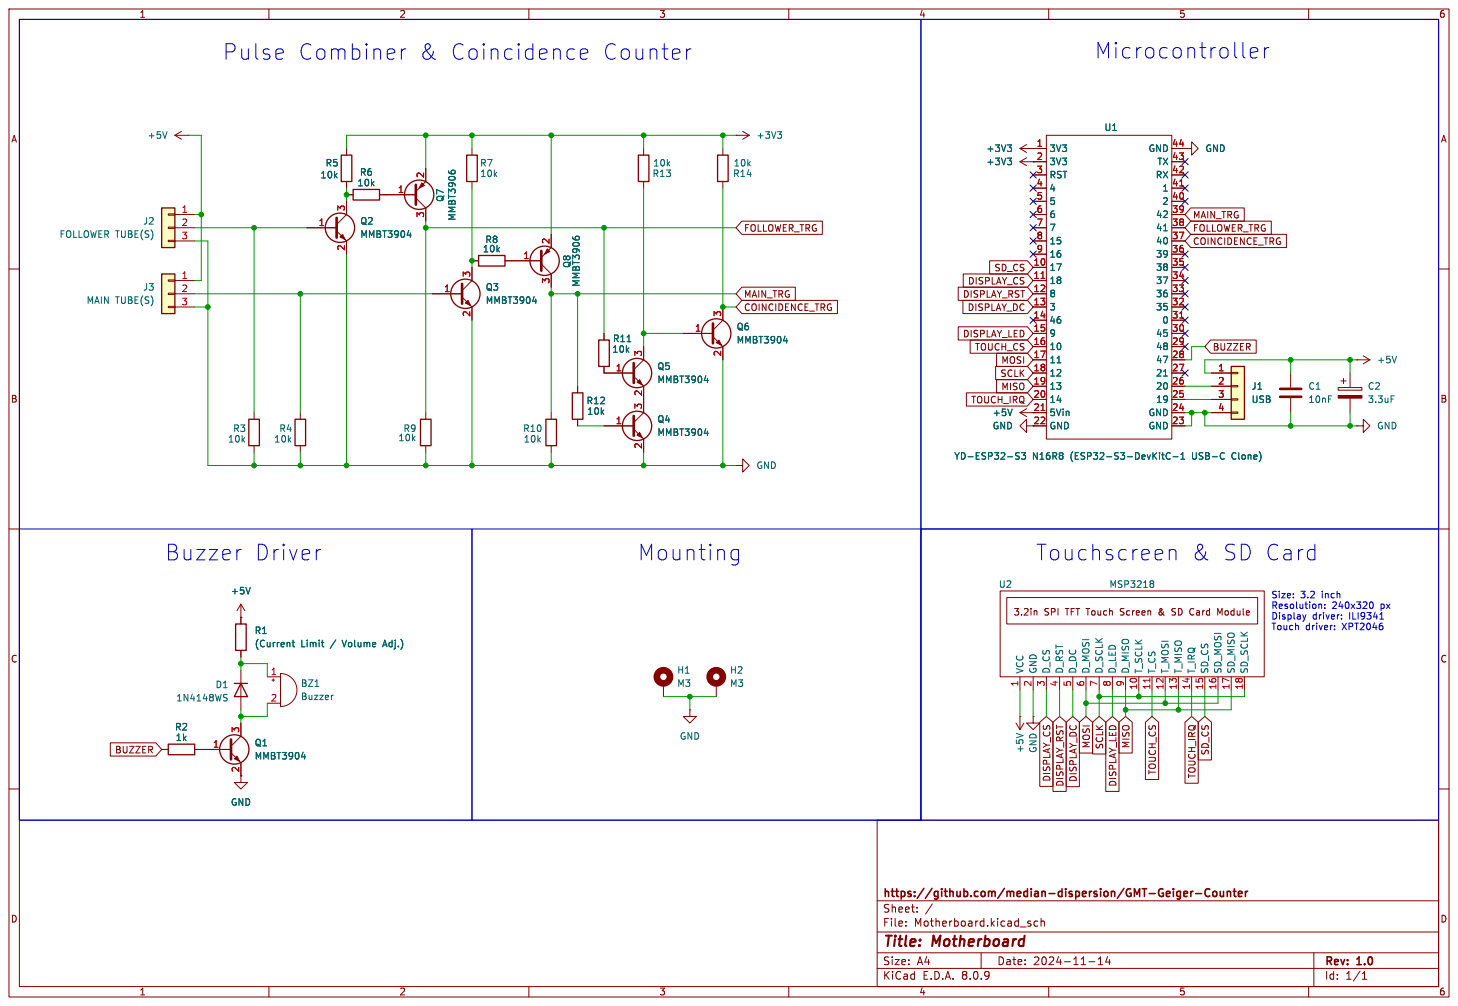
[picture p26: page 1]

3.2in SPI TFT Touch Screen & SD Card Module VCC

File: Motherboard.kicad_sch Sheet: / https://github.com/median-dispersion/GMT-Geiger-Counter

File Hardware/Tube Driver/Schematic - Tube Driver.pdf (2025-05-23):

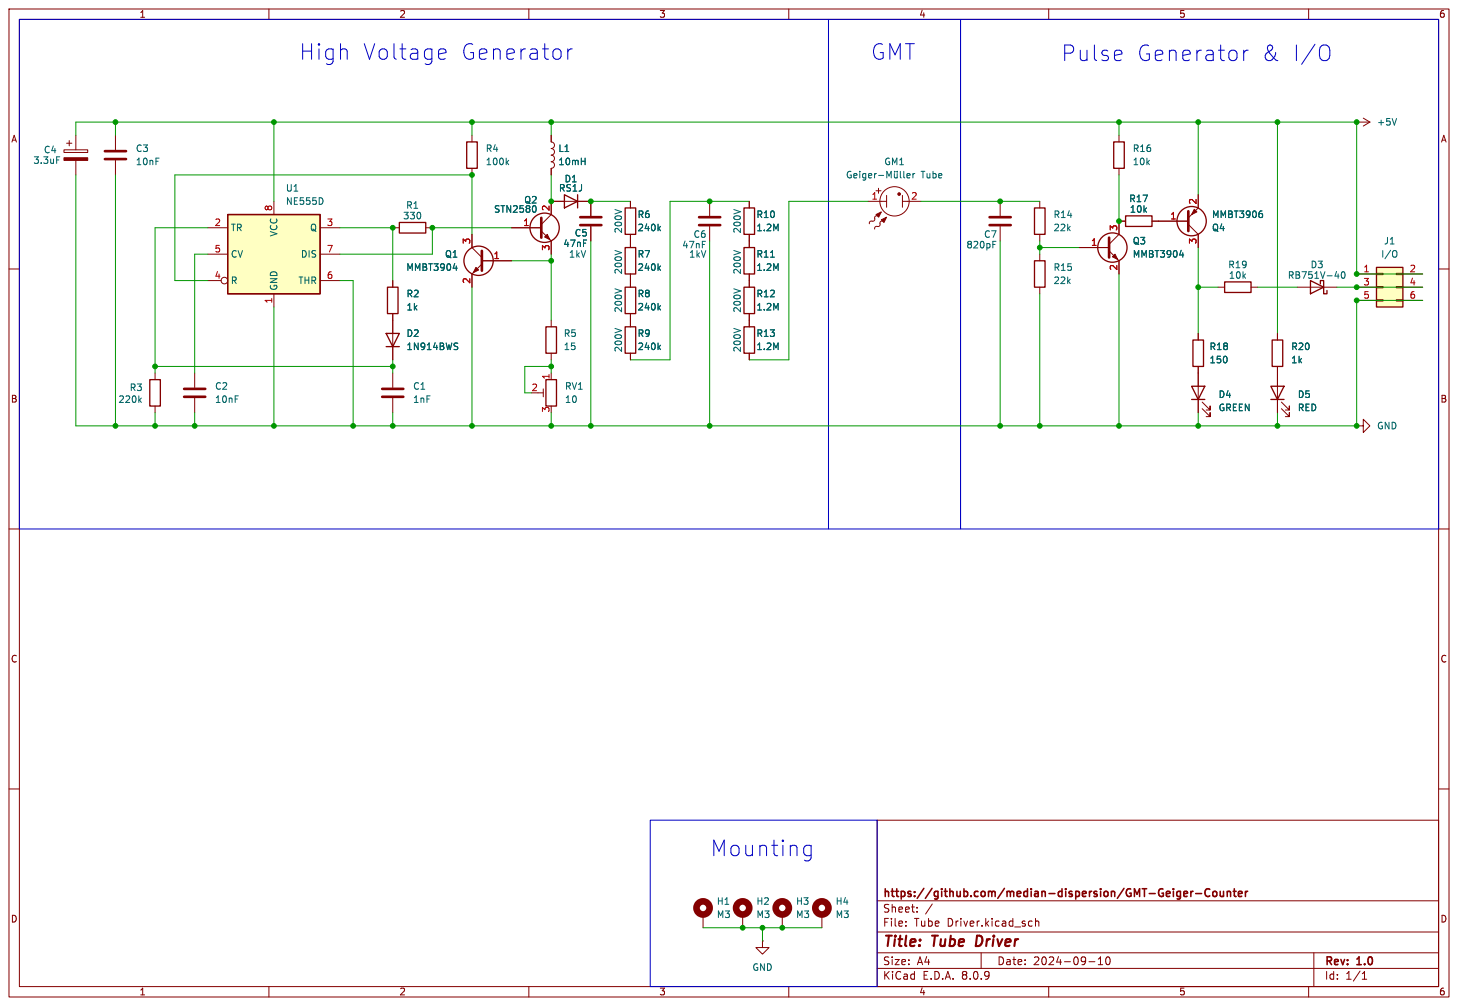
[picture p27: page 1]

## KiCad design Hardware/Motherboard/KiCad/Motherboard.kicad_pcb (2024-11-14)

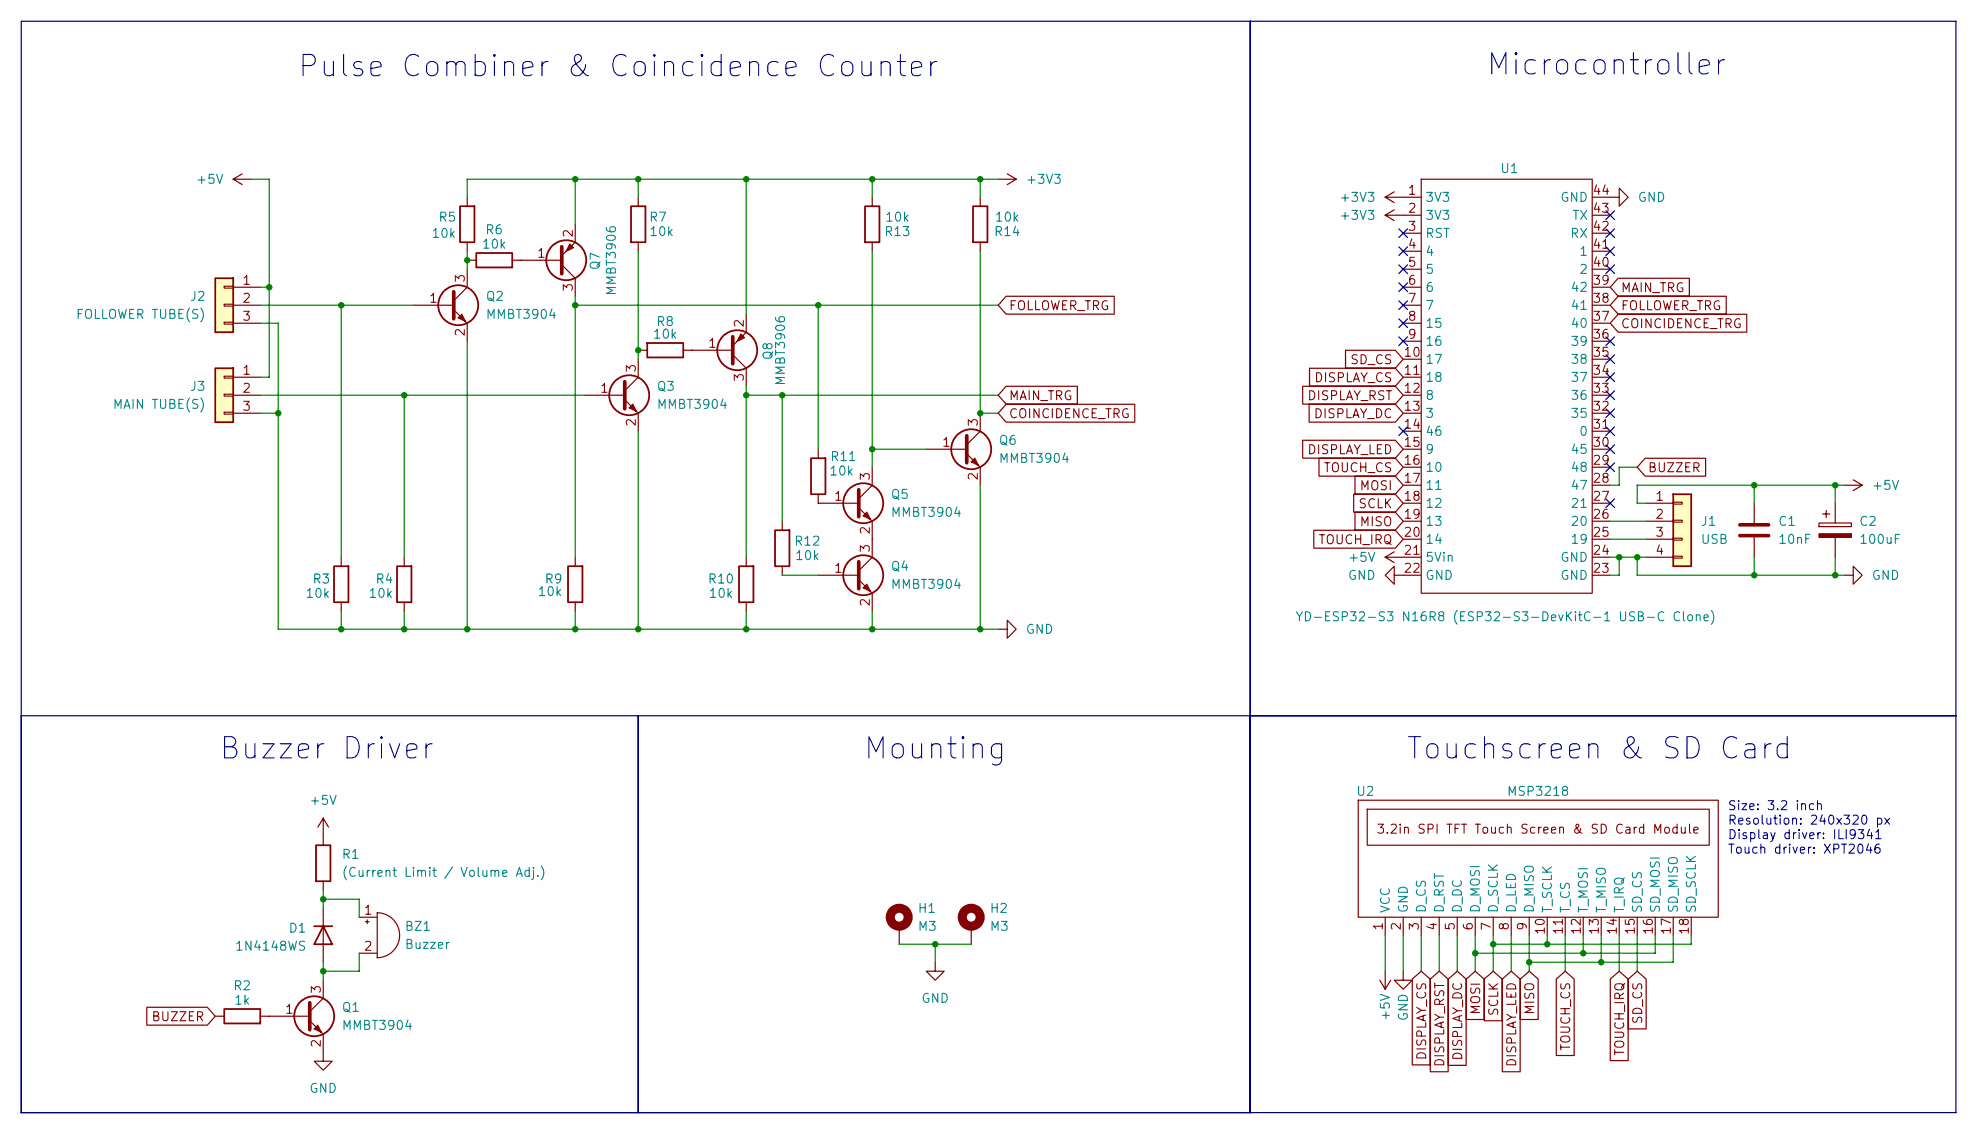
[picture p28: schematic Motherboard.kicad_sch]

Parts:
BZ1: Buzzer; PinHeader_1x02_P2.54mm_Vertical; MPN WT-1209T
C1: 10nF; C_1206_3216Metric_Pad1.33x1.80mm_HandSolder; MPN 885012208112
C2: 100uF; CP_Elec_6.3x5.4; MPN 875105344010
D1: 1N4148WS; D_SOD-323_HandSoldering; MPN 1N4148WS
H1, H2: M3; MountingHole_3.2mm_M3_Pad_Via
J1: USB; USB_Pin_Header; MPN PH1RB-04-UA
J2: FOLLOWER TUBE(S); PinHeader_1x03_P2.54mm_Vertical; MPN PH1RB-03-UA
J3: MAIN TUBE(S); PinHeader_1x03_P2.54mm_Vertical; MPN PH1RB-03-UA
Q1, Q2, Q3, Q4, Q5, Q6: MMBT3904; SOT-23_Handsoldering; MPN MMBT3904
Q7, Q8: MMBT3906; SOT-23_Handsoldering; MPN MMBT3906
R1: (Current Limit / Volume Adj.); R_1206_3216Metric_Pad1.30x1.75mm_HandSolder; MPN RC1206JR-070RL
R2: 1k; R_1206_3216Metric_Pad1.30x1.75mm_HandSolder; MPN RC1206FR-071KL
R3, R4, R5, R6, R7, R8, R9, R10, R11, R12, R13, R14: 10k; R_1206_3216Metric_Pad1.30x1.75mm_HandSolder; MPN RC1206FR-1310KL
U1: YD-ESP32-S3 N16R8 (ESP32-S3-DevKitC-1 USB-C Clone); YD-ESP32-S3_(ESP32-S3-DevKitC-1_USB-C_Clone); MPN YD-ESP32-S3 N16R8
U2: MSP3218; 3.2in_SPI_TFT_Touch_Screen_&_SD_Card_Module; MPN MSP3218

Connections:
+3V3: Q7.2 (E), Q8.2 (E), R5.2, R7.1, R13.1, R14.1, U1.1 (3V3), U1.2 (3V3)
+5V: C1.1, C2.1, J1.1, J2.1, J3.1, R1.1, U1.21 (5Vin), U2.1 (VCC)
BUZZER: R2.1, U1.28 (47)
COINCIDENCE_TRG: Q6.3 (C), R14.2, U1.37 (40)
DISPLAY_CS: U1.11 (18), U2.3 (D_CS)
DISPLAY_DC: U1.13 (3), U2.5 (D_DC)
DISPLAY_LED: U1.15 (9), U2.8 (D_LED)
DISPLAY_RST: U1.12 (8), U2.4 (D_RST)
FOLLOWER_TRG: Q7.3 (C), R9.2, R11.2, U1.38 (41)
GND: C1.2, C2.2, H1.1, H2.1, J1.4, J2.3, J3.3, Q1.2 (E), Q2.2 (E), Q3.2 (E), Q4.2 (E), Q6.2 (E), R3.1, R4.1, R9.1, R10.1, U1.22 (GND), U1.23 (GND), U1.24 (GND), U1.44 (GND), U2.2 (GND)
MAIN_TRG: Q8.3 (C), R10.2, R12.2, U1.39 (42)
MISO: U1.19 (13), U2.9 (D_MISO), U2.13 (T_MISO), U2.17 (SD_MISO)
MOSI: U1.17 (11), U2.6 (D_MOSI), U2.12 (T_MOSI), U2.16 (SD_MOSI)
unnamed: BZ1.1 (+), D1.1 (K), R1.2
unnamed: BZ1.2 (-), D1.2 (A), Q1.3 (C)
unnamed: J1.2, U1.26 (20)
unnamed: J1.3, U1.25 (19)
unnamed: J2.2, Q2.1 (B), R3.2
unnamed: J3.2, Q3.1 (B), R4.2
unnamed: Q1.1 (B), R2.2
unnamed: Q2.3 (C), R5.1, R6.1
unnamed: Q3.3 (C), R7.2, R8.2
unnamed: Q4.1 (B), R12.1
unnamed: Q4.3 (C), Q5.2 (E)
unnamed: Q5.1 (B), R11.1
unnamed: Q5.3 (C), Q6.1 (B), R13.2
unnamed: Q7.1 (B), R6.2
unnamed: Q8.1 (B), R8.1
SCLK: U1.18 (12), U2.7 (D_SCLK), U2.10 (T_SCLK), U2.18 (SD_SCLK)
SD_CS: U1.10 (17), U2.15 (SD_CS)
TOUCH_CS: U1.16 (10), U2.11 (T_CS)
TOUCH_IRQ: U1.20 (14), U2.14 (T_IRQ)

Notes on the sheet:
Microcontroller
Mounting
Buzzer Driver
Touchscreen & SD Card
Size: 3.2 inch Resolution: 240x320 px Display driver: ILI9341 Touch driver: XPT2046
Pulse Combiner & Coincidence Counter

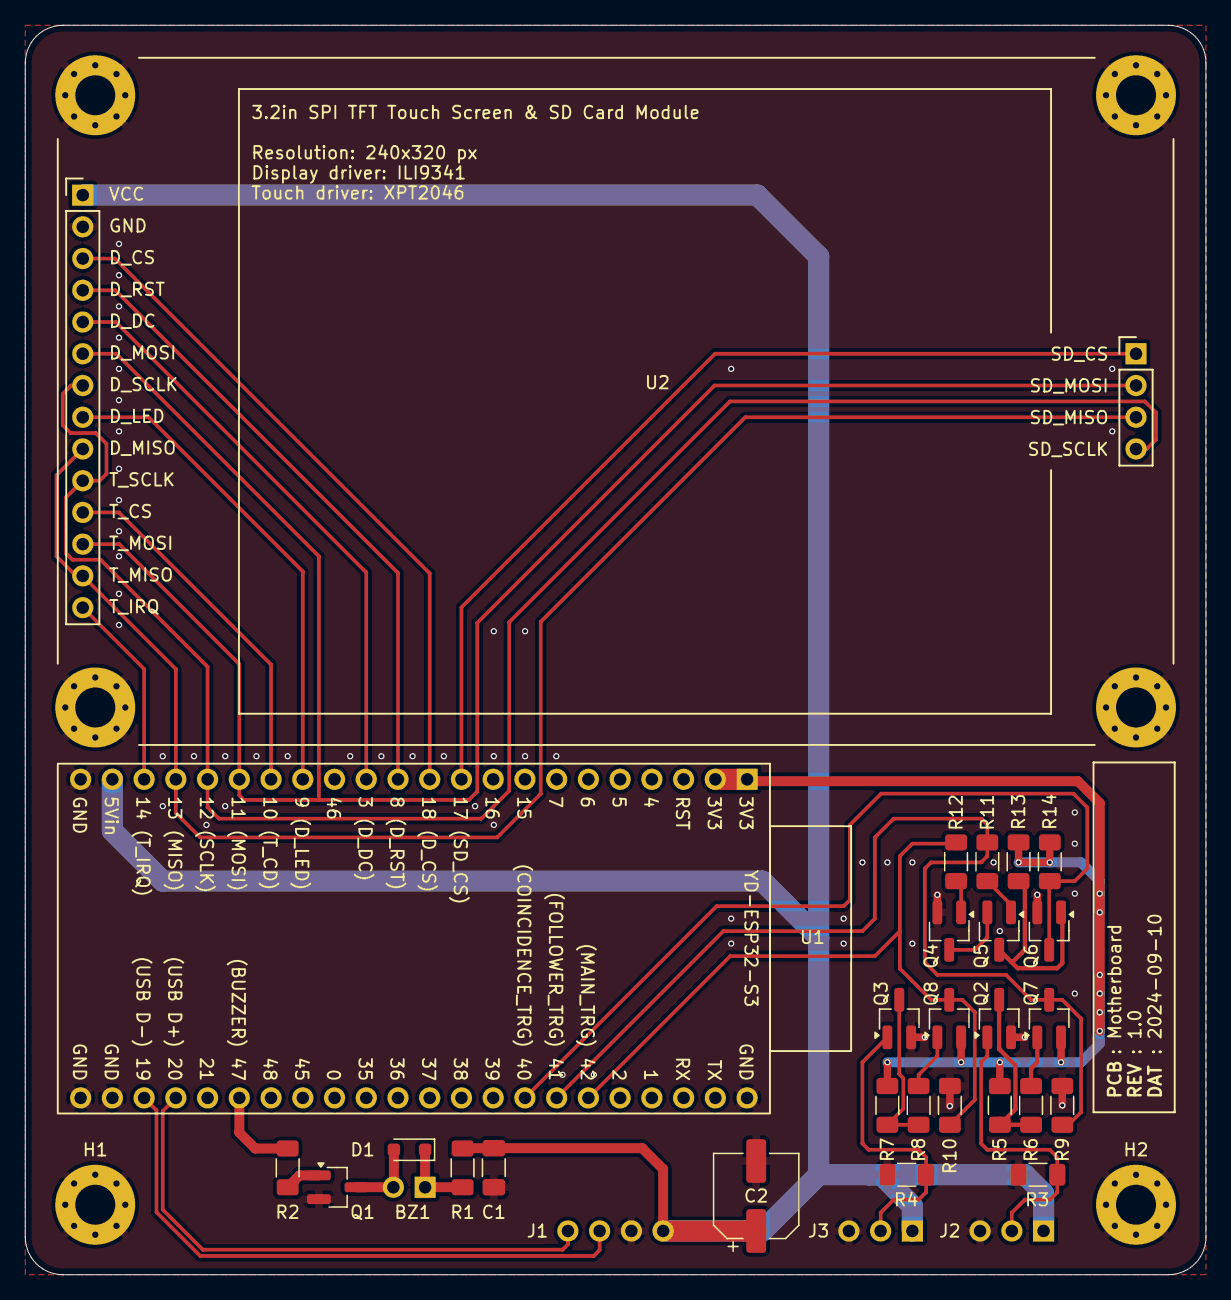
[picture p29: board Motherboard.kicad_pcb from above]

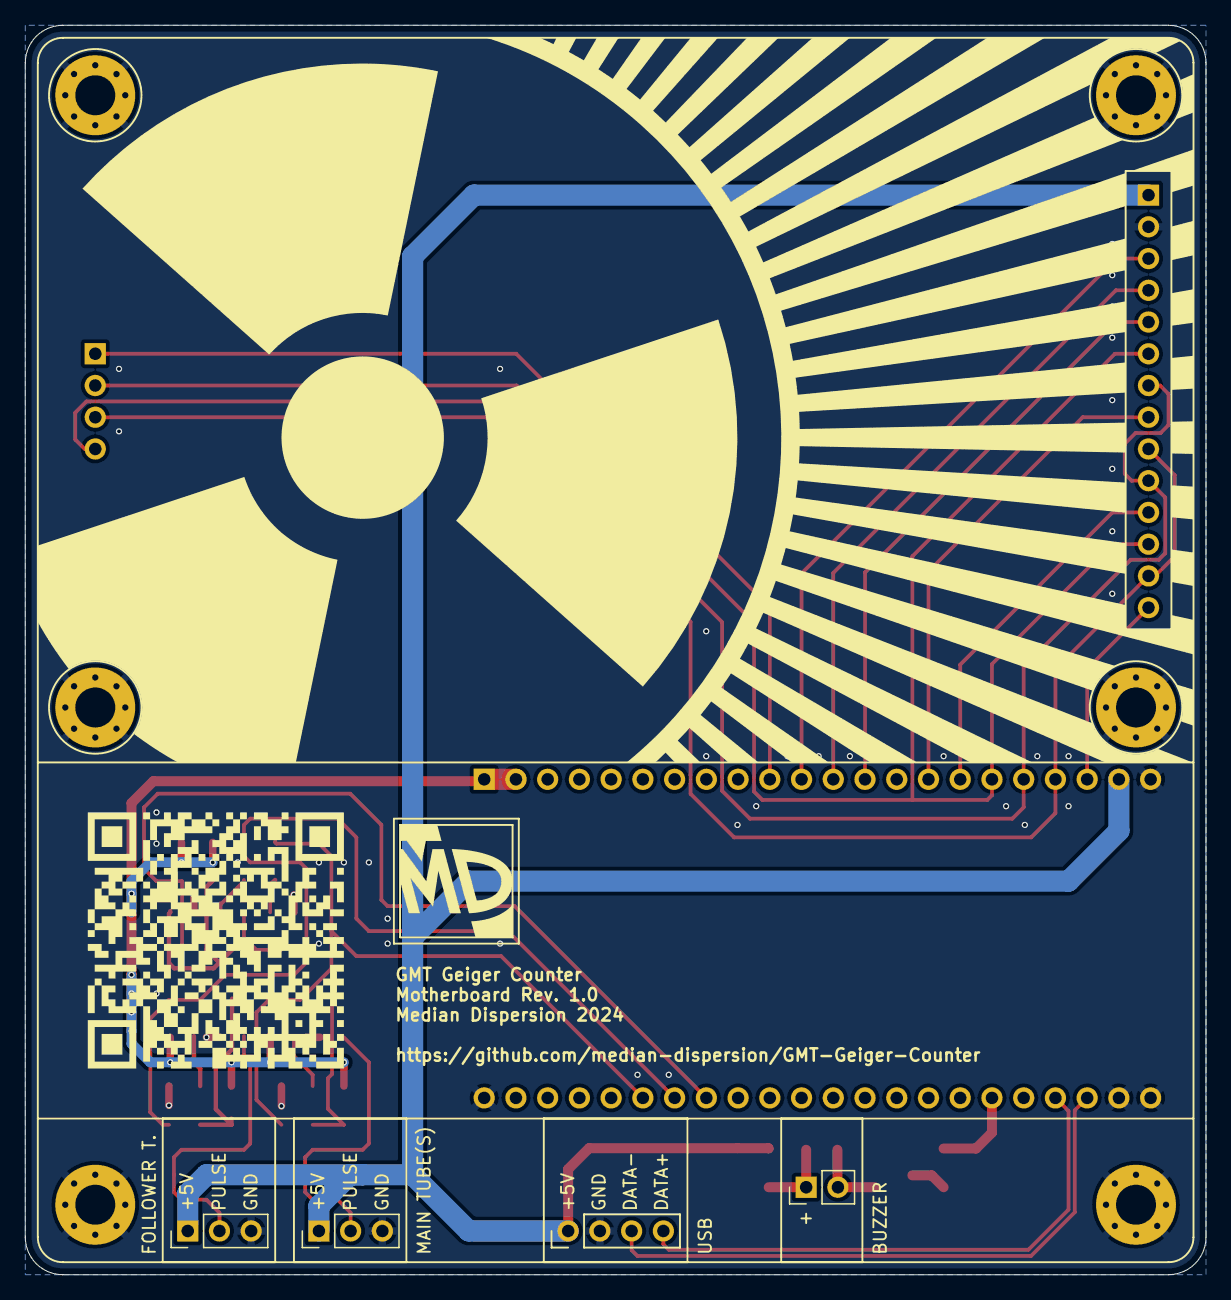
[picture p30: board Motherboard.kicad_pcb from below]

Board: 2 copper layers, 94.5 x 100.0 mm, 33 parts (4 on the bottom side), 32 nets.

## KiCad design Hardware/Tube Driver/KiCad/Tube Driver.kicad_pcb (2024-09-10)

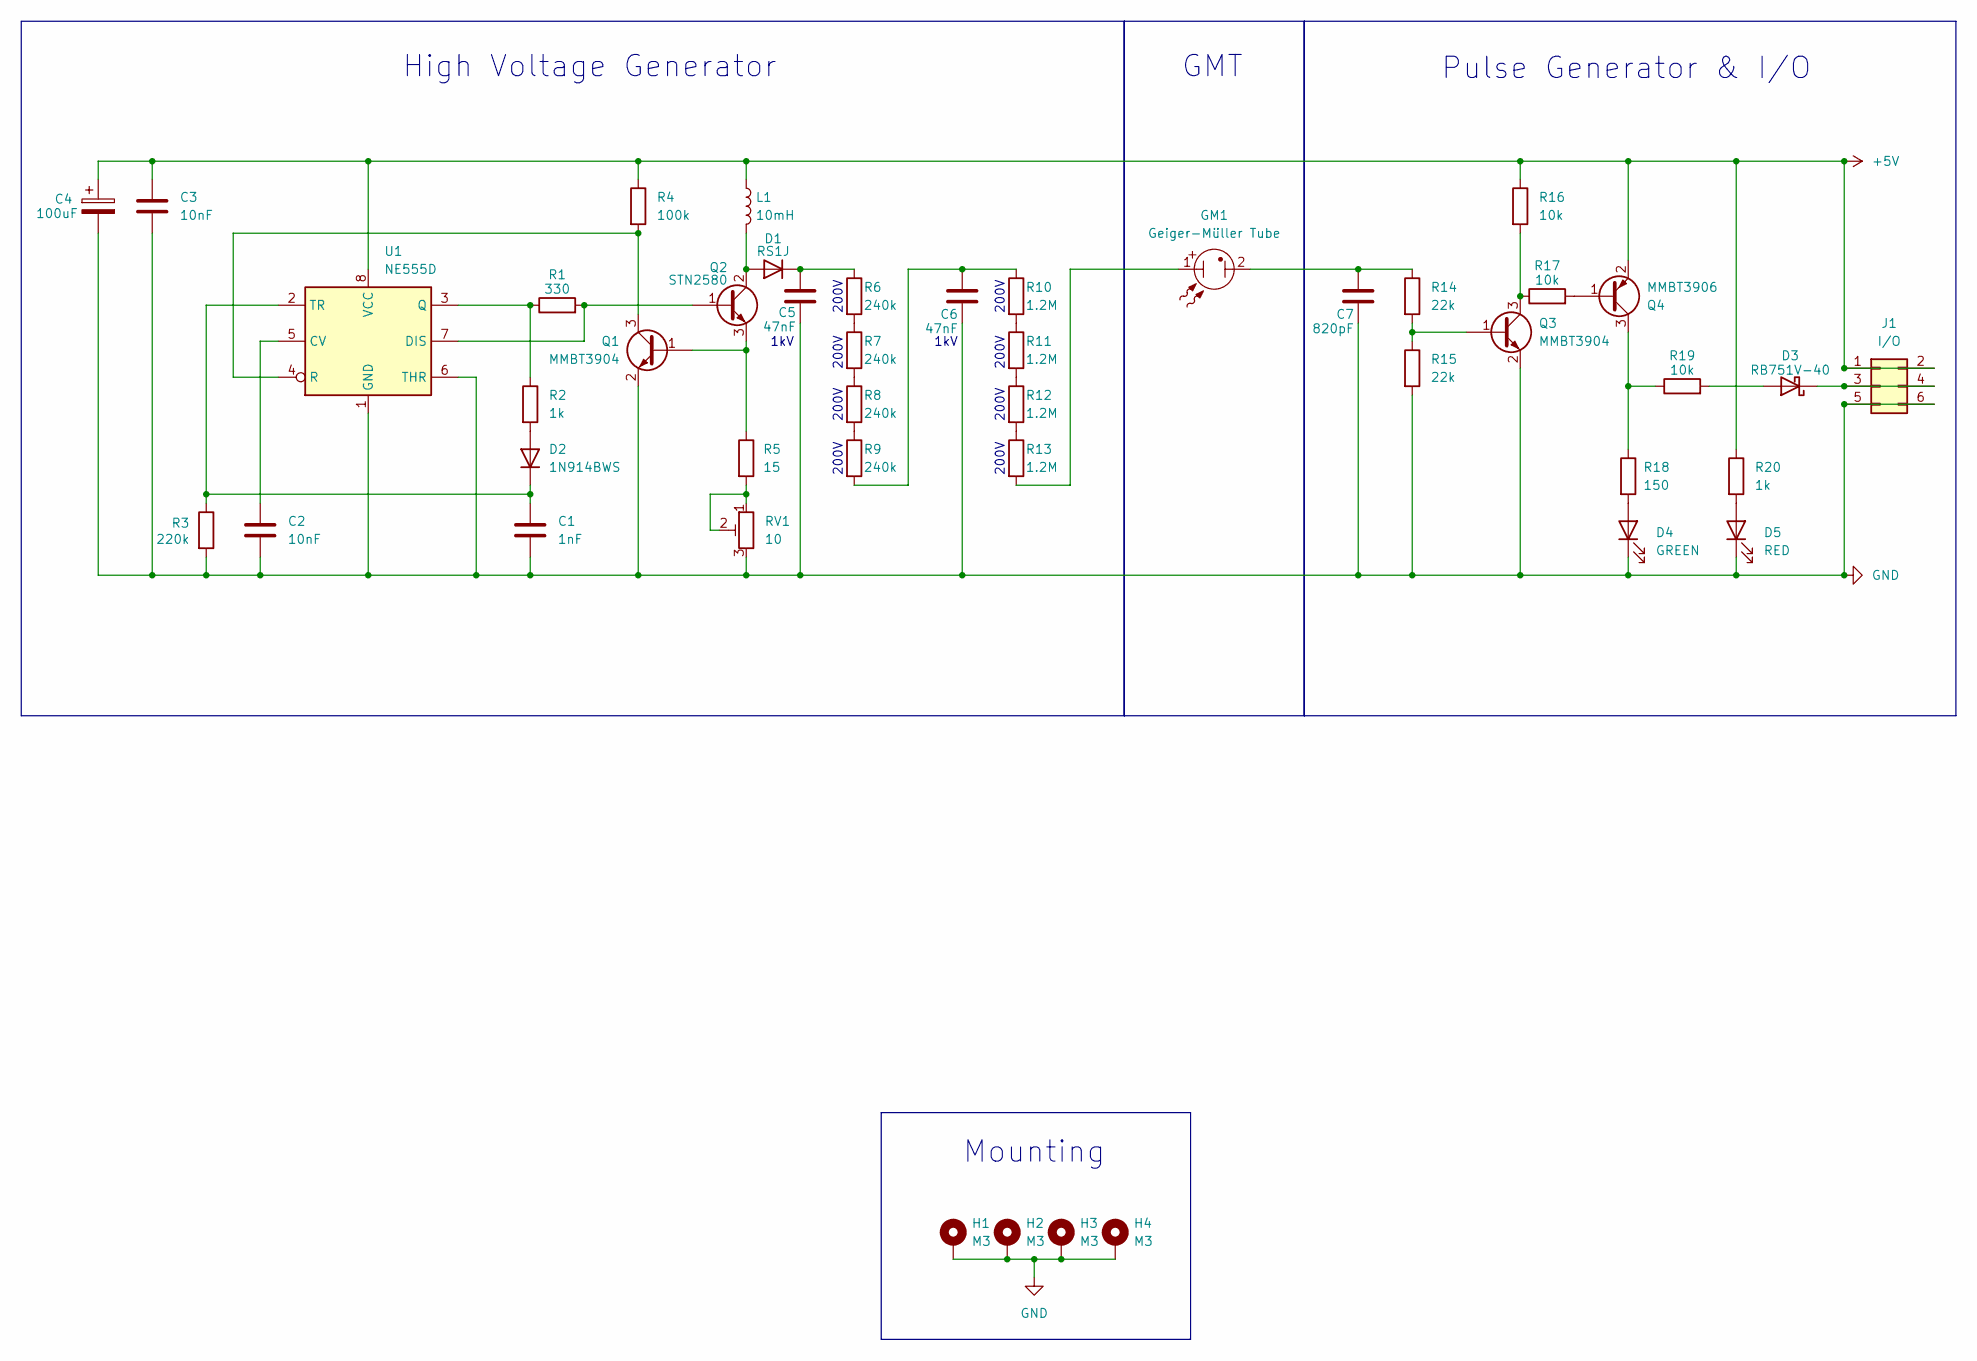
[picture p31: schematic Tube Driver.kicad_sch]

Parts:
C1: 1nF; C_1206_3216Metric_Pad1.33x1.80mm_HandSolder; MPN 885012208046
C2, C3: 10nF; C_1206_3216Metric_Pad1.33x1.80mm_HandSolder; MPN 885012208112
C4: 100uF; CP_Elec_6.3x5.4; MPN 865080243007
C5, C6: 47nF; C_1210_3225Metric_Pad1.33x2.70mm_HandSolder; MPN C1210V473KDRAC7800
C7: 820pF; C_1206_3216Metric_Pad1.33x1.80mm_HandSolder; MPN CC1206FRNPO9BN821
D1: RS1J; D_SMA_HV_Handsoldering; MPN RS1J-13-F
D2: 1N914BWS; D_SOD-323_HandSoldering; MPN 1N914BWS
D3: RB751V-40; D_SOD-323_HandSoldering; MPN RB751V-40_R1_00001
D4: GREEN; LED_1206_3216Metric_Pad1.42x1.75mm_HandSolder; MPN 150120GS75000
D5: RED; LED_1206_3216Metric_Pad1.42x1.75mm_HandSolder; MPN 150120RS75000
GM1: Geiger-Müller Tube; GM_Tube_Mount; MPN FC-102 BRIGHT TIN
H1, H2, H3, H4: M3; MountingHole_3.2mm_M3_Pad_Via
J1: I/O; PinHeader_2x03_P2.54mm_Vertical; MPN PH2-06-UA
L1: 10mH; L_8065_HandSolder; MPN 74404086103
Q1, Q3: MMBT3904; SOT-23_Handsoldering; MPN MMBT3904
Q2: STN2580; SOT-223; MPN STN2580
Q4: MMBT3906; SOT-23_Handsoldering; MPN MMBT3906
R1: 330; R_1206_3216Metric_Pad1.30x1.75mm_HandSolder; MPN RC1206FR-07330RL
R2, R20: 1k; R_1206_3216Metric_Pad1.30x1.75mm_HandSolder; MPN RC1206FR-071KL
R3: 220k; R_1206_3216Metric_Pad1.30x1.75mm_HandSolder; MPN RC1206FR-07220KL
R4: 100k; R_1206_3216Metric_Pad1.30x1.75mm_HandSolder; MPN AC1206FR-07100KL
R5: 15; R_1206_3216Metric_Pad1.30x1.75mm_HandSolder; MPN RC1206FR-0715RL
R6, R7, R8, R9: 240k; R_1206_3216Metric_Pad1.30x1.75mm_HandSolder; MPN RC1206FR-07240KL
R10, R11, R12, R13: 1.2M; R_1206_3216Metric_Pad1.30x1.75mm_HandSolder; MPN RC1206FR-071M2L
R14, R15: 22k; R_1206_3216Metric_Pad1.30x1.75mm_HandSolder; MPN RC1206FR-0722KL
R16, R17, R19: 10k; R_1206_3216Metric_Pad1.30x1.75mm_HandSolder; MPN RC1206FR-1310KL
R18: 150; R_1206_3216Metric_Pad1.30x1.75mm_HandSolder; MPN RC1206FR-13150RL
RV1: 10; RV_3361P; MPN 3361P-1-100GLF
U1: NE555D; SOIC-8_3.9x4.9mm_P1.27mm; MPN NE555D

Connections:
+5V: C3.1, C4.1, J1.1, J1.2, L1.1, Q4.2 (E), R4.1, R16.1, R20.1, U1.8 (VCC)
GND: C1.2, C2.2, C3.2, C4.2, C5.2, C6.2, C7.2, D4.1 (K), D5.1 (K), H1.1, H2.1, H3.1, H4.1, J1.5, J1.6, Q1.2 (E), Q3.2 (E), R3.2, R15.2, RV1.3, U1.1 (GND), U1.6 (THR)
unnamed: C6.1, R9.2, R10.1
unnamed: C7.1, GM1.2, R14.1
unnamed: D1.2 (A), L1.2, Q2.2 (C), Q2.4 (C)
unnamed: C5.1, D1.1 (K), R6.1
unnamed: D2.2 (A), R2.2
unnamed: C1.1, D2.1 (K), R3.1, U1.2 (TR)
unnamed: D3.2 (A), R19.2
unnamed: D3.1 (K), J1.3, J1.4
unnamed: D4.2 (A), R18.2
unnamed: D5.2 (A), R20.2
unnamed: GM1.1, R13.2
unnamed: Q1.1 (B), Q2.3 (E), R5.1
unnamed: Q1.3 (C), R4.2, U1.4 (R)
unnamed: Q2.1 (B), R1.2, U1.7 (DIS)
unnamed: Q3.1 (B), R14.2, R15.1
unnamed: Q3.3 (C), R16.2, R17.1
unnamed: Q4.1 (B), R17.2
unnamed: Q4.3 (C), R18.1, R19.1
unnamed: R5.2, RV1.1, RV1.2
unnamed: R6.2, R7.1
unnamed: R7.2, R8.1
unnamed: R8.2, R9.1
unnamed: R10.2, R11.1
unnamed: R11.2, R12.1
unnamed: R12.2, R13.1
unnamed: C2.1, U1.5 (CV)
unnamed: R1.1, R2.1, U1.3 (Q)

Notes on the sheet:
200V
1kV
GMT
High Voltage Generator
Mounting
Pulse Generator & I/O

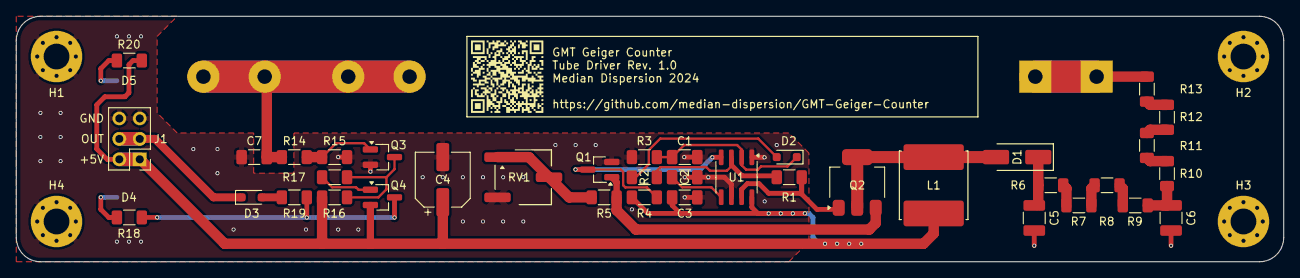
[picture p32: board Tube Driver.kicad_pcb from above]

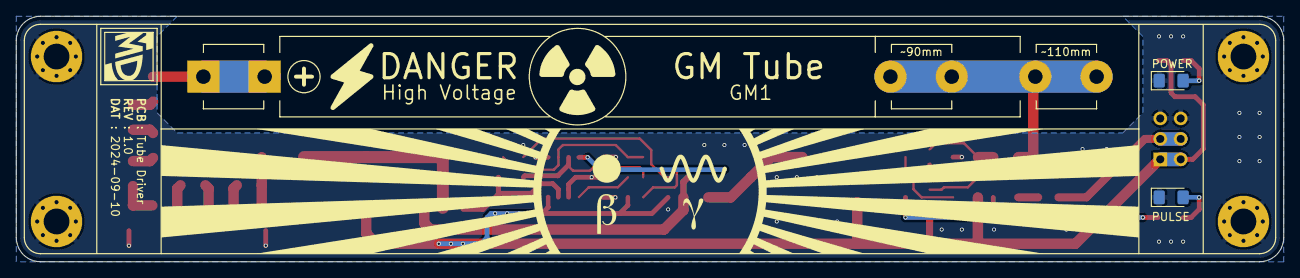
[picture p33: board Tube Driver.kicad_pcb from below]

Board: 2 copper layers, 157.5 x 30.5 mm, 45 parts (3 on the bottom side), 29 nets.

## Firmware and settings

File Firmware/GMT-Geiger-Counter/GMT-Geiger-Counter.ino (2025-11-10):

#include "Arduino.h"
#include "Configuration.h"
#include "Pins.h"
#include "Logger.h"
#include "SDCard.h"
#include "Settings.h"
#include "GeigerCounter.h"
#include "CosmicRayDetector.h"
#include "RandomNumberGenerator.h"
#include "Buzzer.h"
#include "Touchscreen.h"
#include "RGBLED.h"
#include "Wireless.h"
#include "Watchdog.h"

// ------------------------------------------------------------------------------------------------
// Global

// Global variables
bool     PLAYED_DOSE_WARNING           = false;
bool     PLAYED_ROLL_FINISHED          = true;
uint64_t LAST_COUNTS_VALUE             = 0;
uint64_t LAST_COINCIDENCE_EVENTS_VALUE = 0;
uint8_t  LAST_RANDOM_NUMBER_VALUE      = 0;
bool     LAST_DETECTIONS_MUTE_STATE    = false;
bool     LAST_BUZZER_MUTER_STATE       = false;
bool     LAST_RGB_LED_STATE            = true;
uint64_t LOG_TIMER                     = 0;

// Function prototypes
void setup();
void loop();
void setTouchActions();
void setUserSettings();
void audioFeedback();
void visualFeedback();
void dataFeedback();
void goToSleep();
void wakeFromSleep();
void temporaryDetectionsToggle();
void geigerCounterDecreaseIntegrationTime();
void geigerCounterResetIntegrationTime();
void geigerCounterIncreaseIntegrationTime();
void geigerCounterDeselectAllUnits();
void cosmicRayDetectorDisable();
void randomNumberGeneratorIncreaseMinimum();
void randomNumberGeneratorDecreaseMinimum();
void randomNumberGeneratorIncreaseMaximum();
void randomNumberGeneratorDecreaseMaximum();
void randomNumberGeneratorRoll();
void randomNumberGeneratorDisable();
void displayGeigerCounter();
void displayGeigerCounterInfo1();
void displayGeigerCounterInfo2();
void displayGeigerCounterInfo3();
void displayAudioSettings();
void displayDisplaySettings();
void displayRotationConfirmation();
void displayCosmicRayDetector();
void displayDisableCosmicRayDetector();
void displayRadiationHistory();
void displayDisableGeigerCounter();
void displayTrueRNG();
void displayHotspotSettings();
void displayWiFiSettings();
void displaySystemSettings1();
void displaySystemSettings2();
void displaySystemSettings3();
void selectGeigerCounterSieverts();
void selectGeigerCounterRem();
void selectGeigerCounterRontgen();
void selectGeigerCounterGray();
void toggleGeigerCounterAutoIntegration(const bool toggled);
void toggleGeigerCounterAutoRanging(const bool toggled);
void toggleAudioDetections(const bool toggled);
void toggleAudioNotifications(const bool toggled);
void toggleAudioAlerts(const bool toggled);
void toggleAudioInterface(const bool toggled);
void toggleAudioMuteEverything(const bool toggled);
void toggleDisplayState(const bool toggled);
void toggleDisplayAutoTimeout(const bool toggled);
void toggleDisplayLEDState(const bool toggled);
void toggleHotspotState(const bool toggled);
void toggleWiFiSate(const bool toggled);
void toggleSystemSDCardMount(const bool toggled);
void toggleSystemSerialLogging(const bool toggled);
void toggleSystemSDCardLogging(const bool toggled);
void toggleSystemDataLogging(const bool toggled);
void toggleSystemEventLogging(const bool toggled);
void toggleSystemInfoLogging(const bool toggled);
void sendGeigerCounterData();
void sendCosmicRayDetectorData();
void sendLogFileData();
void sendSystemInfoData();
void sendRestartAcknowledgement();
void restart();
void reset();

// ================================================================================================
// Setup
// ================================================================================================
void setup() {

  // Setup hardware pins
  setupPins();

  // Initialize everything
  logger.begin();
  sdCard.begin();
  settings.begin();
  geigerCounter.begin();
  cosmicRayDetector.begin();
  randomNumberGenerator.begin();
  buzzer.begin();
  touchscreen.begin();
  rgbLED.begin();
  wireless.begin();
  watchdog.begin();

  // Set touch actions
  setTouchActions();

  // Load and set the user settings
  setUserSettings();

  // Assign web server endpoints
  wireless.server.on("/data/geiger-counter",          HTTP_GET, sendGeigerCounterData        );
  wireless.server.on("/data/cosmic-ray-detector",     HTTP_GET, sendCosmicRayDetectorData    );
  wireless.server.on("/data/random-number-generator", HTTP_GET, sendRandomNumberGeneratorData);
  wireless.server.on("/data/log",                     HTTP_GET, sendLogFileData              );
  wireless.server.on("/data/system",                  HTTP_GET, sendSystemInfoData           );
  wireless.server.on("/system/restart",               HTTP_PUT, sendRestartAcknowledgement   );

  // Enable geiger counter
  geigerCounter.enable();

  // Enable touchscreen
  touchscreen.enable();

  // Play jingle
  buzzer.play(buzzer.jingle);

}

// ================================================================================================
// Main loop
// ================================================================================================
void loop() {

  // Audio feedback
  audioFeedback();

  // Visual feedback
  visualFeedback();

  // Data feedback
  dataFeedback();

  // Update the random number generator
  randomNumberGenerator.update();

  // Update user settings
  settings.update();

  // Update wireless interface
  wireless.update();

  // Update the watchdog
  watchdog.update();

}

//-------------------------------------------------------------------------------------------------
// Setup functions

// ================================================================================================
// Set touch actions
// ================================================================================================
void setTouchActions() {

  // --------------------------------------------
  // Geiger counter touch actions

  touchscreen.geigerCounter.geigerCounterSetting.action    = displayGeigerCounterInfo1;
  touchscreen.geigerCounter.audioSettings.action           = displayAudioSettings;
  touchscreen.geigerCounter.displaySettings.action         = displayDisplaySettings;
  touchscreen.geigerCounter.goToSleep.action               = goToSleep;
  touchscreen.geigerCounter.decreaseIntegrationTime.action = geigerCounterDecreaseIntegrationTime;
  touchscreen.geigerCounter.resetIntegrationTime.action    = geigerCounterResetIntegrationTime;
  touchscreen.geigerCounter.increaseIntegrationTime.action = geigerCounterIncreaseIntegrationTime;
  touchscreen.geigerCounter.cosmicRayDetector.action       = displayRotationConfirmation;
  touchscreen.geigerCounter.radiationHistory.action        = displayRadiationHistory;
  touchscreen.geigerCounter.trueRNG.action                 = displayDisableGeigerCounter;
  touchscreen.geigerCounter.hotspotSettings.action         = displayHotspotSettings;
  touchscreen.geigerCounter.wifiSettings.action            = displayWiFiSettings;
  touchscreen.geigerCounter.systemSettings.action          = displaySystemSettings1;

  // --------------------------------------------
  // Geiger counter info 1 touch actions

  touchscreen.geigerCounterInfo1.back.action     = displayGeigerCounter;
  touchscreen.geigerCounterInfo1.next.action     = displayGeigerCounterInfo2;
  touchscreen.geigerCounterInfo1.previous.action = displayGeigerCounterInfo3;

  // --------------------------------------------
  // Geiger counter info 2 touch actions

  touchscreen.geigerCounterInfo2.back.action     = displayGeigerCounter;
  touchscreen.geigerCounterInfo2.next.action     = displayGeigerCounterInfo3;
  touchscreen.geigerCounterInfo2.previous.action = displayGeigerCounterInfo1;

  // --------------------------------------------
  // Geiger counter info 2 touch actions

  touchscreen.geigerCounterInfo3.back.action          = displayGeigerCounter;
  touchscreen.geigerCounterInfo3.next.action          = displayGeigerCounterInfo1;
  touchscreen.geigerCounterInfo3.previous.action      = displayGeigerCounterInfo2;
  touchscreen.geigerCounterInfo3.autoIntegrate.action = toggleGeigerCounterAutoIntegration;
  touchscreen.geigerCounterInfo3.autoRange.action     = toggleGeigerCounterAutoRanging;
  touchscreen.geigerCounterInfo3.sieverts.action      = selectGeigerCounterSieverts;
  touchscreen.geigerCounterInfo3.rem.action           = selectGeigerCounterRem;
  touchscreen.geigerCounterInfo3.rontgen.action       = selectGeigerCounterRontgen;
  touchscreen.geigerCounterInfo3.gray.action          = selectGeigerCounterGray;

  // --------------------------------------------
  // Audio settings touch actions

  touchscreen.audioSettings.back.action           = displayGeigerCounter;
  touchscreen.audioSettings.detections.action     = toggleAudioDetections;
  touchscreen.audioSettings.notifications.action  = toggleAudioNotifications;
  touchscreen.audioSettings.alerts.action         = toggleAudioAlerts;
  touchscreen.audioSettings.interface.action      = toggleAudioInterface;
  touchscreen.audioSettings.muteEverything.action = toggleAudioMuteEverything;

  // --------------------------------------------
  // Display settings touch actions

  touchscreen.displaySettings.back.action    = displayGeigerCounter;
  touchscreen.displaySettings.display.action = toggleDisplayState;
  touchscreen.displaySettings.timeout.action = toggleDisplayAutoTimeout;
  touchscreen.displaySettings.rgbLED.action  = toggleDisplayLEDState;

  // --------------------------------------------
  // Rotation confirmation touch actions

  touchscreen.rotationConfirmation.back.action    = displayGeigerCounter;
  touchscreen.rotationConfirmation.confirm.action = displayCosmicRayDetector;

  // --------------------------------------------
  // Cosmic ray detector touch actions

  touchscreen.cosmicRayDetector.back.action  = displayDisableCosmicRayDetector;
  touchscreen.cosmicRayDetector.mute.action  = temporaryDetectionsToggle;
  touchscreen.cosmicRayDetector.sleep.action = goToSleep;

  // --------------------------------------------
  // Disable cosmic ray detector touch actions

  touchscreen.disableCosmicRayDetector.back.action    = displayCosmicRayDetector;
  touchscreen.disableCosmicRayDetector.confirm.action = cosmicRayDetectorDisable;
  touchscreen.disableCosmicRayDetector.dismiss.action = displayGeigerCounter;

  // --------------------------------------------
  // Radiation history touch actions

  touchscreen.radiationHistory.back.action = displayGeigerCounter;

  // --------------------------------------------
  // Disable Geiger counter actions

  touchscreen.disableGeigerCounter.back.action    = displayGeigerCounter;
  touchscreen.disableGeigerCounter.confirm.action = displayTrueRNG;
  touchscreen.disableGeigerCounter.dismiss.action = displayGeigerCounter;

  // --------------------------------------------
  // True RNG touch actions

  touchscreen.trueRNG.back.action            = randomNumberGeneratorDisable;
  touchscreen.trueRNG.increaseMinimum.action = randomNumberGeneratorIncreaseMinimum;
  touchscreen.trueRNG.decreaseMinimum.action = randomNumberGeneratorDecreaseMinimum;
  touchscreen.trueRNG.increaseMaximum.action = randomNumberGeneratorIncreaseMaximum;
  touchscreen.trueRNG.decreaseMaximum.action = randomNumberGeneratorDecreaseMaximum;
  touchscreen.trueRNG.roll.action            = randomNumberGeneratorRoll;
  touchscreen.trueRNG.mute.action            = temporaryDetectionsToggle;
  touchscreen.trueRNG.sleep.action           = goToSleep;

  // --------------------------------------------
  // Hotspot settings touch actions

  touchscreen.hotspotSettings.back.action   = displayGeigerCounter;
  touchscreen.hotspotSettings.enable.action = toggleHotspotState;

  // --------------------------------------------
  // WiFi settings touch actions

  touchscreen.wifiSettings.back.action   = displayGeigerCounter;
  touchscreen.wifiSettings.enable.action = toggleWiFiSate;

  // --------------------------------------------
  // System settings 1 touch actions

  touchscreen.systemSettings1.back.action          = displayGeigerCounter;
  touchscreen.systemSettings1.next.action          = displaySystemSettings2;
  touchscreen.systemSettings1.previous.action      = displaySystemSettings3;
  touchscreen.systemSettings1.sdCardMounted.action = toggleSystemSDCardMount;
  touchscreen.systemSettings1.serialLogging.action = toggleSystemSerialLogging;
  touchscreen.systemSettings1.sdCardLogging.action = toggleSystemSDCardLogging;
  touchscreen.systemSettings1.dataLogging.action   = toggleSystemDataLogging;
  touchscreen.systemSettings1.eventLogging.action  = toggleSystemEventLogging;
  touchscreen.systemSettings1.systemLogging.action = toggleSystemInfoLogging;

  // --------------------------------------------
  // System settings 2 touch actions

  touchscreen.systemSettings2.back.action          = displayGeigerCounter;
  touchscreen.systemSettings2.next.action          = displaySystemSettings3;
  touchscreen.systemSettings2.previous.action      = displaySystemSettings1;

  // --------------------------------------------
  // System settings 3 touch actions

  touchscreen.systemSettings3.back.action          = displayGeigerCounter;
  touchscreen.systemSettings3.restart.action       = restart;
  touchscreen.systemSettings3.reset.action         = reset;
  touchscreen.systemSettings3.next.action          = displaySystemSettings1;
  touchscreen.systemSettings3.previous.action      = displaySystemSettings2;

  // --------------------------------------------
  // Hotspot settings touch actions

  touchscreen.hotspotSettings.back.action   = displayGeigerCounter;
  touchscreen.hotspotSettings.enable.action = toggleHotspotState;

  // --------------------------------------------
  // WiFi settings touch actions

  touchscreen.wifiSettings.back.action   = displayGeigerCounter;
  touchscreen.wifiSettings.enable.action = toggleWiFiSate;
  
  // --------------------------------------------
  // Sleep screen actions

  touchscreen.sleepScreen.wakeup.action = wakeFromSleep;

}

// ================================================================================================
// Load and set the user settings
// ================================================================================================
void setUserSettings() {

  // Load settings from SD card
  settings.load();

  // --------------------------------------------
  // Logger settings

  logger.setSerialLoggingState(settings.data.parameters.logger.serial);
  logger.setSDCardLoggingState(settings.data.parameters.logger.sdCard);
  logger.setLogLevelState(Logger::DATA, settings.data.parameters.logger.data);
  logger.setLogLevelState(Logger::EVENT, settings.data.parameters.logger.event);
  logger.setLogLevelState(Logger::SYSTEM, settings.data.parameters.logger.system);

  // --------------------------------------------
  // Geiger counter settings

  geigerCounter.setAutoIntegrateState(settings.data.parameters.geigerCounter.autoIntegrate);
  geigerCounter.setAutoRangeState(settings.data.parameters.geigerCounter.autoRange);
  geigerCounter.setMeasurementUnit(settings.data.parameters.geigerCounter.measurementUnit);

  // --------------------------------------------
  // Buzzer settings

  buzzer.detections.setMuteState(settings.data.parameters.buzzer.detections);
  buzzer.notifications.setMuteState(settings.data.parameters.buzzer.notifications);
  buzzer.alerts.setMuteState(settings.data.parameters.buzzer.alerts);
  buzzer.interface.setMuteState(settings.data.parameters.buzzer.interface);
  buzzer.setMuteState(settings.data.parameters.buzzer.muteEverything);

  // --------------------------------------------
  // Display settings

  touchscreen.setTimeoutState(settings.data.parameters.display.timeout);
  rgbLED.setLEDState(settings.data.parameters.display.rgbLED);

  // --------------------------------------------
  // Wireless settings

  wireless.setHotspotState(settings.data.parameters.wireless.hotspot);
  // wireless.setWiFiState(settings.data.parameters.wireless.wifi);

  // --------------------------------------------
  // Load settings in the last state variables

  LAST_DETECTIONS_MUTE_STATE = settings.data.parameters.buzzer.detections;
  LAST_BUZZER_MUTER_STATE    = settings.data.parameters.buzzer.muteEverything;
  LAST_RGB_LED_STATE         = settings.data.parameters.display.rgbLED;

}

//-------------------------------------------------------------------------------------------------
// Loop functions
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

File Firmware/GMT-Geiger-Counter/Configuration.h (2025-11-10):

// The main configuration file for the GMT-Geiger-Counter firmware

// ================================================================================================
// Geiger counter / tube settings
// ================================================================================================

// Enable pulse counting for a specific tube header
// If only one tube is connected, disable the follower tube pin header
// If two or more tubes are connected, split them evenly and enable both pin headers
// 0 = Disabled, 1 = Enabled
#define ENABLE_MAIN_TUBE     1
#define ENABLE_FOLLOWER_TUBE 0

// The total number of tubes connected to the motherboard (both main and follower)
// This will be used to divide the equivalent dose by the number of tubes to get an accurate reading
#define TOTAL_NUMBER_OF_TUBES 1

// Conversion factor to convert counts per minute to microsieverts per hour
// This is different for each type of tube and must be calculated from the datasheet
// SMB-20: 0.005011429 [Ra226]
#define TUBE_CONVERSION_FACTOR_CPM_TO_USVH 0.005011429

// The median length of a pulse in microseconds
// This is not the tube's dead time, but the length of the pulse the tube driver board generates
// When daisy-chaining multiple tubes on one pin header, pulses from different tubes might occur simultaneously or overlap
// To capture overlapping pulses, the total pulse length must be divided by the median single pulse length for a tube to get the actual number of counts
// To get an accurate value for a specific tube type, use the Calibrate-Pulse-Length firmware to measure it
// This value will only be used if 3 or more tubes are connected and set through the TOTAL_NUMBER_OF_TUBES definition
// SBM-20: 122 µs
#define TUBE_MEDIAN_PULSE_LENGTH_MICROSECONDS 122

// The minimum length of a pulse in microseconds
// Related to TUBE_MEDIAN_PULSE_LENGTH_MICROSECONDS
// Will also be measured by the Calibrate-Pulse-Length firmware
// SBM-20: 116 µs
#define TUBE_MINIMUM_PULSE_LENGTH_MICROSECONDS 116

// The maximum length of a pulse in microseconds
// Related to TUBE_MEDIAN_PULSE_LENGTH_MICROSECONDS
// Will also be measured by the Calibrate-Pulse-Length firmware
// SBM-20: 124 µs
#define TUBE_MAXIMUM_PULSE_LENGTH_MICROSECONDS 124

// Noise threshold, the minimum length in microseconds a pulse must be to count as an actual pulse
// Anything shorter than that will be ignored as noise
// This should be around 30% of the minimum pulse length in microseconds
// This value should not be changed!
#define TUBE_NOISE_THRESHOLD_MICROSECONDS (TUBE_MINIMUM_PULSE_LENGTH_MICROSECONDS * 30 / 100)

// Tube pulse time remainder threshold
// When calculating the number of counts for a given pulse time, the total pulse length will be divided by the median single pulse length (TUBE_MEDIAN_PULSE_LENGTH_MICROSECONDS)
// This threshold will determine if the pulse time that will remain after the division is counted as an additional full pulse
// This should be around 20% of the maximum pulse length in microseconds
// This value will only be used if 3 or more tubes are connected and set through the TOTAL_NUMBER_OF_TUBES definition
// This value should not be changed!
#define TUBE_PULSE_REMAINDER_THRESHOLD_MICROSECONDS (TUBE_MAXIMUM_PULSE_LENGTH_MICROSECONDS * 20 / 100)

// Coincidence tube pulse threshold
// Ideally, the coincidence tube pulse length would be 100% of the normal pulse length because both Geiger tubes should trigger almost at the same time
// But in reality, due to circuit delays, there might be a delay between pulses, and therefore the coincidence pulse could fall short of what it should be
// This is why the coincidence tube pulse threshold in microseconds should be around 50% of the regular pulse length in microseconds
// This value should not be changed!
#define TUBE_COINCIDENCE_THRESHOLD_MICROSECONDS (TUBE_MINIMUM_PULSE_LENGTH_MICROSECONDS * 50 / 100)

// Name of the tube type
// This can be set to an arbitrary string and is only used for logging
#define TUBE_TYPE_NAME "SBM-20"

// Radiation rating values in microsieverts per hour
// These values are used to classify the recorded radiation level
#define RADIATION_RATING_NORMAL_USVH   0.0
#define RADIATION_RATING_ELEVATED_USVH 0.5
#define RADIATION_RATING_MEDIUM_USVH   2.0
#define RADIATION_RATING_HIGH_USVH     10.0
#define RADIATION_RATING_EXTREME_USVH  20.0
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

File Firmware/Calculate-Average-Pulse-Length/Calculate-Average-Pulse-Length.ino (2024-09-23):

/*

  Calculates the average pulse time for a Geiger-Müller tube
  This is not the tube's dead time, but the pulse length the tube driver generates for that specific tube!

  Median Dispersion 2024
  https://github.com/median-dispersion/GMT-Geiger-Counter

*/

// ================================================================================================
// User configuration
// ================================================================================================

// The pin, the GM tube is connected to
// When using the tube drive board and connected to the main tube header, this doesn't need to be changed
#define TUBE_PIN 42

// How many samples to taken before averaging them
#define SAMPLE_COUNT 100

// Noise threshold, the minimum length in microseconds a pulse must be to count as an actual pulse
// Anything shorter than that will be ignored as noise
#define NOISE_THRESHOLD_MICROSECONDS 30

// ================================================================================================
// Global variables
// ================================================================================================
volatile uint64_t totalPulseTimeMicroseconds = 0;
volatile uint64_t maxPulseTimeMicroseconds = 0;
volatile uint64_t minPulseTimeMicroseconds = UINT64_MAX;
volatile uint16_t pulseIndex = 0;
volatile uint64_t tubeTimer = 0;
uint64_t loopTimer = 0;
uint8_t finished = false;

// ================================================================================================
// ISR for measuring pulse length
// ================================================================================================
void IRAM_ATTR measurePulseLength() {

  // If the pin is HIGH (rising edge)
  if (digitalRead(TUBE_PIN) == HIGH) {

    // Capture the starting time in microseconds
    tubeTimer = micros();

  // If the pin is LOW (falling edge)
  } else {

    // Calculate the difference between the current and starting time in microseconds
    uint64_t pulseLength = micros() - tubeTimer;

    // If the pulse length is higher than the noise threshold
    if (pulseLength > NOISE_THRESHOLD_MICROSECONDS) {

      // Add the pulse length to the total pulse time
      totalPulseTimeMicroseconds += pulseLength;

      // Set the maximum pulse length
      if (pulseLength > maxPulseTimeMicroseconds) { maxPulseTimeMicroseconds = pulseLength; }

      // Set the minimum pulse length
      if (pulseLength < minPulseTimeMicroseconds) { minPulseTimeMicroseconds = pulseLength; }

      // Increase the index by one until the sample count is reached
      if (pulseIndex < SAMPLE_COUNT) { pulseIndex++; }

    }

  }

}

// ================================================================================================
// Main setup
// ================================================================================================
void setup() {

  // Setup serial communication
  Serial.begin(115200);
  delay(1000);
  Serial.println("\n\n\n");

  // Set the pin mode for the tube pin to INPUT
  pinMode(TUBE_PIN, INPUT);

  // Attach a hardware interrupt to the tube pin that calls an ISR when the pin state is changing
  attachInterrupt(digitalPinToInterrupt(TUBE_PIN), measurePulseLength, CHANGE);

}

// ================================================================================================
// Main loop
// ================================================================================================
void loop() {

  // Check if samples are still being taken
  if (pulseIndex < SAMPLE_COUNT) {

    // Every second
    if (millis() - loopTimer >= 1000) {

      // Print status message to the serial console
      Serial.println("Collecting samples (" + String(pulseIndex) + "/" + String(SAMPLE_COUNT) + ")...");

      // Update the loop timer to the current time
      loopTimer = millis();

    }

  // If sampling process has finished
  } else {

    // Check if result was not already printed to the serial console
    if(!finished) {

      // Detach the hardware interrupt to stop the measurement
      detachInterrupt(digitalPinToInterrupt(TUBE_PIN));

      // Calculate the average pulse time in microseconds
      uint16_t averagePulseLengthMicroseconds = round(static_cast<double>(totalPulseTimeMicroseconds) / SAMPLE_COUNT);

      // Print the result to the serial console
      Serial.println("\n\n\n");
      Serial.println("Finished!");
      Serial.println("=========\n");
      Serial.println("Total accumulative pulse time for " + String(SAMPLE_COUNT) + " samples: " + String(totalPulseTimeMicroseconds) + " µs");
      Serial.println("Maximum pulse length: " + String(maxPulseTimeMicroseconds) + "µs");
      Serial.println("Minimum pulse length: " + String(minPulseTimeMicroseconds) + "µs");
      Serial.println("Average pulse length: " + String(averagePulseLengthMicroseconds) + "µs");
      
      // Set the finished flag to true
      finished = true;

    }

  }

}

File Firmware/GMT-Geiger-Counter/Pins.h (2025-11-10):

#ifndef PINS_H
#define PINS_H

#include "Arduino.h"
#include "Configuration.h"

void setupPins() {

    // Set pin modes
    // -------------

    // SPI Pins
    pinMode(DISPLAY_CS_PIN, OUTPUT);
    pinMode(TOUCH_CS_PIN, OUTPUT);
    pinMode(SD_CS_PIN, OUTPUT);
    pinMode(SCK_PIN, OUTPUT);
    pinMode(MOSI_PIN, OUTPUT);
    pinMode(MISO_PIN, INPUT);

    // Display pins
    pinMode(DISPLAY_LED_PIN, OUTPUT);
    pinMode(DISPLAY_RST_PIN, OUTPUT);
    pinMode(DISPLAY_DC_PIN, OUTPUT);

    // Touchscreen pins
    pinMode(TOUCH_IRQ_PIN, INPUT);

    // Tube pins
    pinMode(MAIN_TRG_PIN, INPUT);
    pinMode(FOLLOWER_TRG_PIN, INPUT);
    pinMode(COINCIDENCE_TRG_PIN, INPUT);

    // Other pins
    pinMode(BUZZER_PIN, OUTPUT);
    pinMode(RGB_LED_PIN, OUTPUT);

    // Set pin states
    // --------------

    // SPI Pins
    digitalWrite(DISPLAY_CS_PIN, HIGH);
    digitalWrite(TOUCH_CS_PIN, HIGH);
    digitalWrite(SD_CS_PIN, HIGH);
    digitalWrite(SCK_PIN, LOW);
    digitalWrite(MOSI_PIN, LOW);

    // Display pins
    digitalWrite(DISPLAY_LED_PIN, LOW);
    digitalWrite(DISPLAY_RST_PIN, HIGH);
    digitalWrite(DISPLAY_DC_PIN, HIGH);

    // Other pins
    pinMode(BUZZER_PIN, LOW);
    pinMode(RGB_LED_PIN, LOW);

}

#endif

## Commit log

2024-09-04 Tube Driver Rev. 1.0
    [Tube Driver.kicad_pcb, Tube Driver.kicad_sch]
2024-09-06 Added BoM, updated component values and PCB
    [BoM - Tube Driver.csv, Tube Driver.kicad_pcb, Tube Driver.kicad_sch]
2024-09-06 Added Gerber for manufacturing
    [Tube Driver-B_Cu.gbr, Tube Driver-B_Mask.gbr, Tube Driver-B_Paste.gbr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]
2024-09-06 Fixed broken footprint
    [Tube Driver-B_Cu.gbr, Tube Driver-B_Mask.gbr, Tube Driver-B_Paste.gbr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]
2024-09-06 Added symbols and footprints
    [Motherboard.kicad_pcb, Motherboard.kicad_sch]
2024-09-06 Added Motherboard schematic Rev. 1.0
    [Motherboard.kicad_sch]
2024-09-08 Motherboard PCB Rev. 1.0
    [Motherboard.kicad_pcb, Motherboard.kicad_sch]
2024-09-10 Added BoM for motherboard
    [BoM - Motherboard.csv, Motherboard.kicad_pcb, Motherboard.kicad_sch]
2024-09-10 Fixed disconnected pad
    [Motherboard.kicad_pcb]
2024-09-10 Added motherboard Gerber for manufacturing
    [Motherboard-B_Cu.gbr, Motherboard-B_Mask.gbr, Motherboard-B_Paste.gbr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]
2024-09-10 Fixed component value typo
    [Tube Driver.kicad_pcb, Tube Driver.kicad_sch]
2024-09-10 Updated Gerber
    [Motherboard-B_Cu.gbr, Motherboard-B_Mask.gbr, Motherboard-B_Paste.gbr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]
2024-09-10 Updated PCB screenshot
2024-09-18 Updated BoM
    [BoM - Tube Driver.csv, Tube Driver.kicad_sch]
2024-09-22 Added firmware
    [Configuration.h]
2024-10-03 Added Geiger counter class
    [Configuration.h]
2024-10-03 Added Buzzer class
    [Configuration.h]
2024-10-18 Added mobile case files
    [Mobile Case.blend]
2024-10-18 Added tube driver model
    [Mobile Case.blend]
2024-10-20 Added bottom case shell
    [Mobile Case.blend]
2024-11-11 Added top case shell & support elements
    [Bottom Shell Triple Tube.stl, Display Spacer x4.stl, HV Shield.stl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]
2024-11-14 Changed component value, fixed typos & fixed small mistakes
    [BoM - Motherboard.csv, BoM - Tube Driver.csv, Motherboard.kicad_pcb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]
2024-11-15 Fixed some things on the 3D model
    [HV Shield.stl, Light Pipes.stl, Mobile Case.blend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]
2025-01-25 Updated main firmware, adding touchscreen support
    [Configuration.h]
2025-01-27 Added display rotation functionality and cosmic ray detector screen
    [Configuration.h]
2025-01-29 Fixed type conversion and calculation issues
    [Configuration.h]
2025-01-29 Added radiation history screen
    [Configuration.h]
2025-01-31 Updated radiation history screen
    [Configuration.h]
2025-02-03 Added memory watchdog
    [Configuration.h]
2025-02-05 Added wireless interfaces
    [Configuration.h]
2025-02-12 Added bare-bones web interface and updated firmware so that the WiFi credentials can be changed via the web interface
    [Configuration.h]
2025-02-13 Added logger to main firmware
    [Configuration.h]
2025-02-13 Made WiFi connection non-blocking
    [Configuration.h]
2025-02-14 Added display auto timeout to the main firmware
    [Configuration.h]
2025-02-15 Added a bunch of small memory optimizations to reduce RAM usage
    [Configuration.h]
2025-02-16 Added more measurement units and an auto range feature
    [Configuration.h]
2025-02-16 Fixed a small issue when alerts were muted no other sound would play
    [GMT-Geiger-Counter.ino]
2025-02-16 Made WiFi settings persistent between reboots by storing them in the non-volatile memory
    [Configuration.h]
2025-02-27 Refactored main firmware and updated UI
    [Configuration.h]
2025-03-03 Updated 3D case model
    [Bottom Shell Double Tube.stl, Bottom Shell Triple Tube.stl, Top Shell.stl]
2025-03-13 Added radiation rating and updated logging
    [Configuration.h]
2025-03-19 Updated Geiger counter web-app
    [Configuration.h]
2025-03-21 Added local settings storage to the web-app and changed some UI elements in the main firmware
    [Configuration.h]
2025-04-29 Added SD card wrapper and rewrote logger
    [Configuration.h]
2025-04-29 Refactored wireless interface
    [Configuration.h]
2025-04-29 Added persistent settings storage and logging functionality
    [Configuration.h]
2025-05-01 Refactored Geiger counter
    [Configuration.h]
2025-05-01 Refactored buzzer
    [Configuration.h]
2025-05-01 Added touchscreen files
    [Configuration.h]
2025-05-04 Removed wireless for testing, reimplemented most functions and fixed a bunch of small things
    [Configuration.h]
2025-05-04 Added wireless features back
2025-05-05 Added RGB LED
    [Configuration.h]
2025-05-08 Updated event logging
    [Configuration.h]
2025-05-09 Added wireless logger
2025-05-23 Updated wireless and serial loggers
2025-05-23 Updated the decoupling capacitor to make it more USB 'compliant'
    [BoM - Motherboard.csv, BoM - Tube Driver.csv, Motherboard.kicad_sch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]
2025-06-05 Refactored logger tools
    [Configuration.h]
2025-06-17 Updated API endpoints
    [Configuration.h]
2025-06-18 Added WiFi settings web app and fixed small bugs in the other web app components.
    [Configuration.h]
2025-06-25 Updated firmware
    [Configuration.h]
2025-06-27 Added case stands
    [22.5 Degree Case Stand x1.stl, 22.5 Degree Case Stand x2.stl, 45 Degree Case Stand x1.stl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]
2025-06-29 Updated mobile case
    [BoM - Mobile Case.csv, Display Cover.stl]
2025-06-30 Fixed 3D model
    [Display Cover.stl]
2025-08-03 Redesigned thinner case stands to use less filament
    [22.5 Degree Case Stand x1.stl, 22.5 Degree Case Stand x2.stl, 45 Degree Case Stand x1.stl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]
2025-08-03 Updated the WiFi interface to automatically reconnect on loss or timeout #6
    [Configuration.h]
2025-08-04 Fixed display timeout resetting user settings #7
    [Configuration.h]
2025-08-05 Added multi-tube daisy chain measurement support and fixed an additional bug with issue #7
    [Configuration.h]
2025-08-05 Updated touch icons and addes 3 system settings screen
    [Configuration.h]
2025-08-06 Added absorbed dose readout feature
    [Configuration.h]
2025-08-07 Small bug fixes
    [Configuration.h]
2025-08-07 Updated wireless interface
    [Configuration.h]
2025-08-10 Added true random number generator interface
    [Configuration.h]
2025-08-11 Minor bug fixes
    [Configuration.h]
2025-08-12 Updated API endpoints and data output
    [Configuration.h]
2025-09-21 Reverted to the old coincidence tube logic (Issue #8) and made the history line thicker
    [Configuration.h]
2025-11-10 Added manual pin setup to prevent rare SPI bus conflicts
    [Configuration.h]
2025-11-20 Updated display cover
    [Display Cover.stl]
2025-11-22 Added case labels
